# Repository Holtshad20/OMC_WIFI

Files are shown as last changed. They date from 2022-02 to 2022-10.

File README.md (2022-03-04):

# OMC WIFI

Proyecto de dispositivo medidor/protector conectado a una red a través de Wi-Fi y monitoreado con un servidor inicialmente interno a la red.

## Dispositivo medidor

### Hardware
Versión actual: 1.0\
Estado: Diseño PCB a la espera de enviar a fábrica.

**Listo**
- Diseño Esquemático KiCAD
- Diseño PCB KiCAD
- GERBERS

**Por hacer**
- Soldar componentes a PCB
- Realizar pruebas con software

Rango voltaje: 100 - 240 V RMS\
Máxima corriente: 20 A RMS - Limitado a 15 A con fusible

### Software
Versión actual: -\
Estado: Creación de códigos separados para posterior unificación.

#### Mediciones voltaje y corriente
Estado: A la espera de dispositivos que consuman mayor potencia para realizar más pruebas.

##### Listo
- Código medición voltaje y corriente.
- Realizar pruebas con distintos niveles de voltaje.

##### Por hacer
- Realizar pruebas con dispositivos que consuman mayor potencia (> 25W).

Rango voltaje: 70 - 240 V RMS\
Rango corriente: 0.2 - 15 A RMS\
*Nota:* Los mímimos en las lecturas se deben al ruido en la conversión AD. Es probable que se reduzca el ruido en PCB.

#### Accionamiento de relay
Estado: En proceso de desarrollo y pruebas

##### Listo
- Código de accionamiento de relay de acuerdo con nivel de voltaje.
- Realizar pruebas con valores de voltaje enviados por comunicación serial.
- Histéresis.

##### Por hacer
- Accionar relay cuando haya sobrecorriente
- Realizar pruebas con mediciones de voltaje real.
- Añadir inicio retardado para caso multidispositivo.

#### Configuración inicial - Conexión Dispositivo-Wi-Fi (AutoConnect)
Estado: En proceso de desarrollo y pruebas.

##### Listo
Por redactar

##### Por hacer
Por redactar

#### Conexión con servidor
Estado: No se ha iniciado.

##### Por hacer
- Implementación de MQTT

#### Integración de códigos
Estado: No se ha iniciado.
##### Por hacer
- Buscar forma de integrar usando FreeRTOS
- Comprobar funcionamiento de códigos integrados evitando interrupciones mutuas.

## Servidor
Estado: No se ha iniciado

**Por hacer**
- Implementación de MQTT en Raspberry Pi

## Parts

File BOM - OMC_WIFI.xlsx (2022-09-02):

Item | Número de Parte (SKU) | Descripción | Link | Precio Unitario | Cantidad | Precio Extendido
1.1 | ESP32-WROOM-32E | Microcontrolador ESP32 |  | $0.00 | 1 | $0.00
1.2 | PZEM-004T | Módulo de monitorización de energía PZEM-004T |  | $0.00 | 1 | $0.00
1.3 | SLA-03VDC-SL-C | Relé 250VAC/30VDC para 3.3v (En caso de no encontrarse, buscar la versión de 5v SLA-05VDC-SL-C) |  | $0.00 | 1 | $0.00
1.4 | HLK-PM01 | Convertidor 100 - 240 VAC a 5VDC/3W |  | $0.00 | 1 | $0.00
1.5 | B07F7W91LC 8541740602 | Level Shifter HiLetgo 3.3V - 5V (4 canales IIC I2C) |  | $0.00 | 1 | $0.00
1.6 | B08CDMZMDN CK0437 | Regulador de 5V a 3.3V |  | $0.00 | 1 | $0.00
2.1 | --- | Conector de alimentación AC macho (NEMA 5-15) |  | $0.00 | 1 | $0.00
2.2 | --- | Conector de alimentación AC hembra (NEMA 5-15) |  | $0.00 | 1 | $0.00
2.3 | --- | Diodo LED SMD verde |  | $0.00 | 1 | $0.00
2.4 | --- | Diodo LED SMD rojo |  | $0.00 | 1 | $0.00
2.5 | --- | Fusible de 15A |  | $0.00 | 1 | $0.00
2.6 | --- | Socket para fusible de 15A (par) |  | $0.00 | 1 | $0.00
2.7 | --- | Cable para suminitro de 100-240 VAC (es el cable que pasa por el toroide) |  | $0.00 | 1 | $0.00
2.8 | --- | Cable para switch de encendido y apagado |  | $0.00 | 3 | $0.00
 |  | Resistencia |  | $0.00 |  | $0.00
 |  |  |  | $0.00 |  | $0.00
 |  |  |  | $0.00 |  | $0.00
 |  |  |  | $0.00 |  | $0.00
 |  |  |  | $0.00 |  | $0.00
 |  |  |  | $0.00 |  | $0.00
 |  |  |  | $0.00 |  | $0.00
 |  |  |  | $0.00 |  | $0.00
 |  |  |  | $0.00 |  | $0.00
 |  |  |  | $0.00 |  | $0.00
 |  |  |  | Total $ |  | $0.00

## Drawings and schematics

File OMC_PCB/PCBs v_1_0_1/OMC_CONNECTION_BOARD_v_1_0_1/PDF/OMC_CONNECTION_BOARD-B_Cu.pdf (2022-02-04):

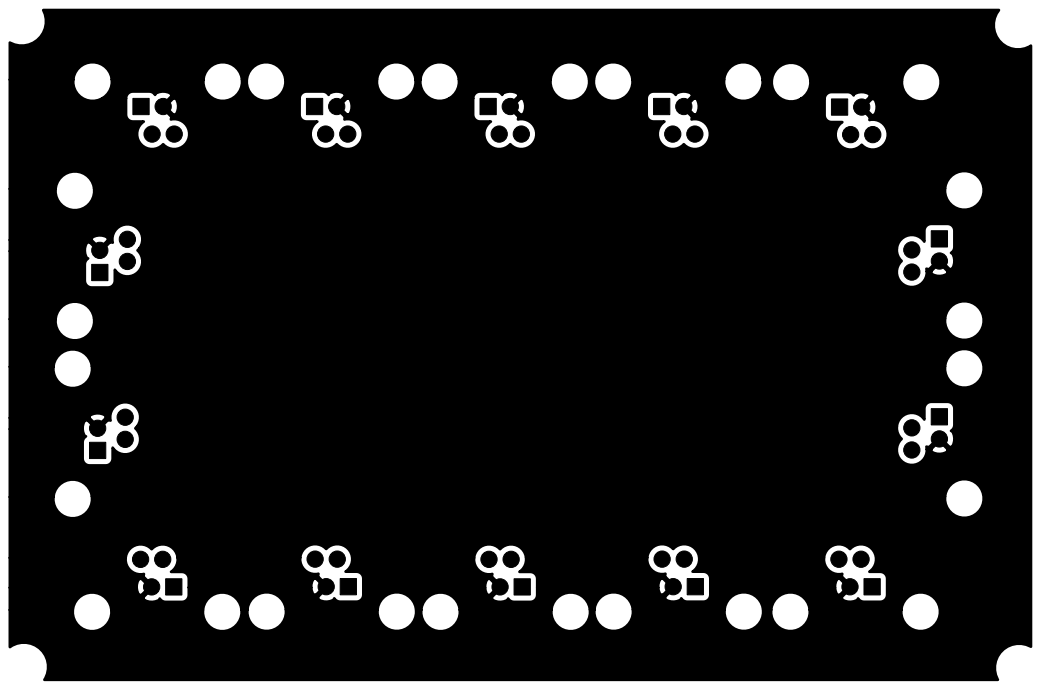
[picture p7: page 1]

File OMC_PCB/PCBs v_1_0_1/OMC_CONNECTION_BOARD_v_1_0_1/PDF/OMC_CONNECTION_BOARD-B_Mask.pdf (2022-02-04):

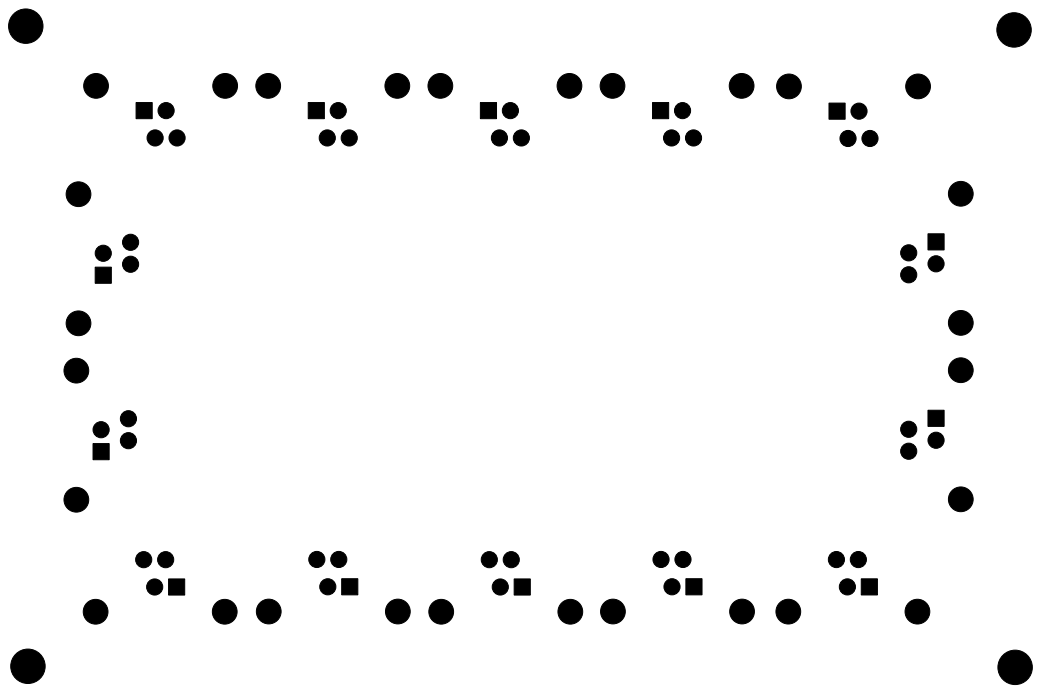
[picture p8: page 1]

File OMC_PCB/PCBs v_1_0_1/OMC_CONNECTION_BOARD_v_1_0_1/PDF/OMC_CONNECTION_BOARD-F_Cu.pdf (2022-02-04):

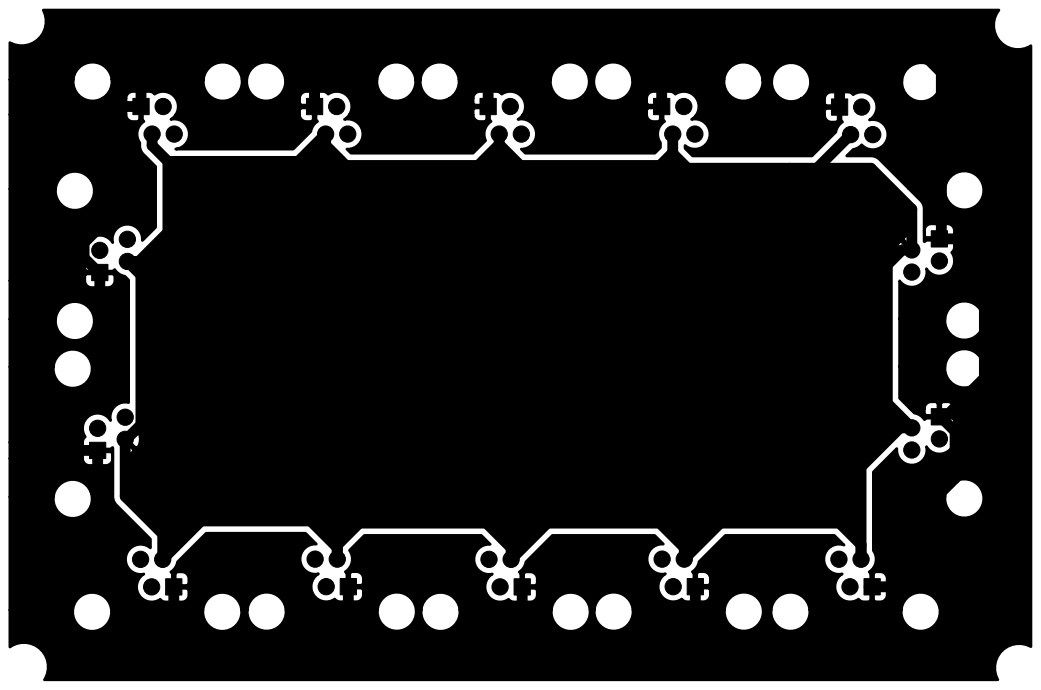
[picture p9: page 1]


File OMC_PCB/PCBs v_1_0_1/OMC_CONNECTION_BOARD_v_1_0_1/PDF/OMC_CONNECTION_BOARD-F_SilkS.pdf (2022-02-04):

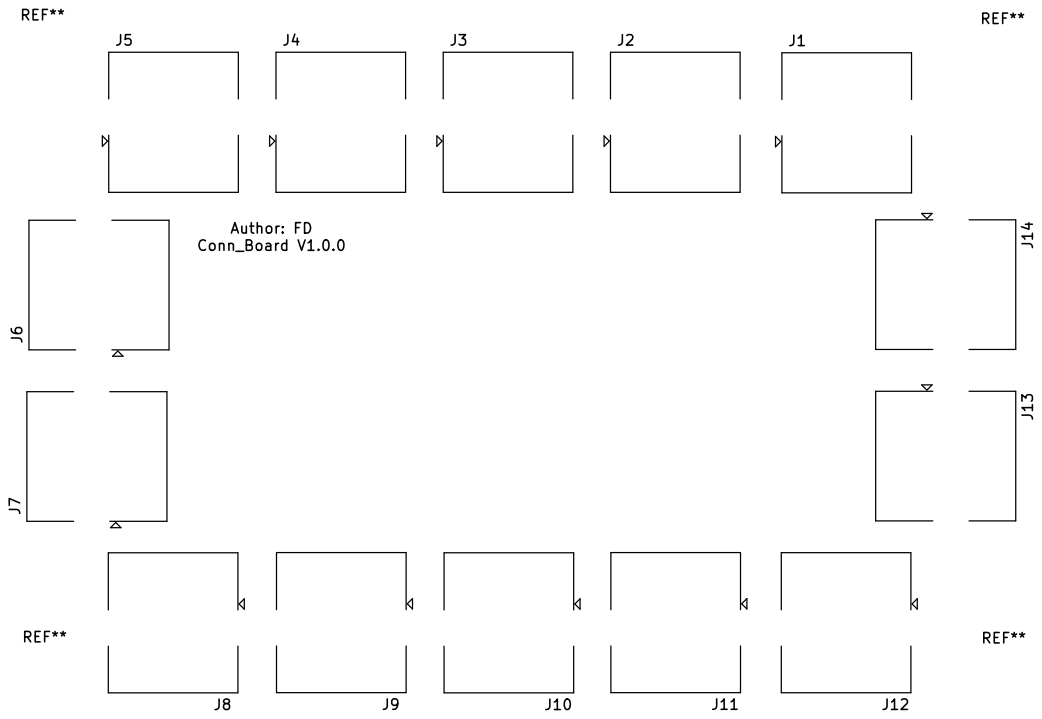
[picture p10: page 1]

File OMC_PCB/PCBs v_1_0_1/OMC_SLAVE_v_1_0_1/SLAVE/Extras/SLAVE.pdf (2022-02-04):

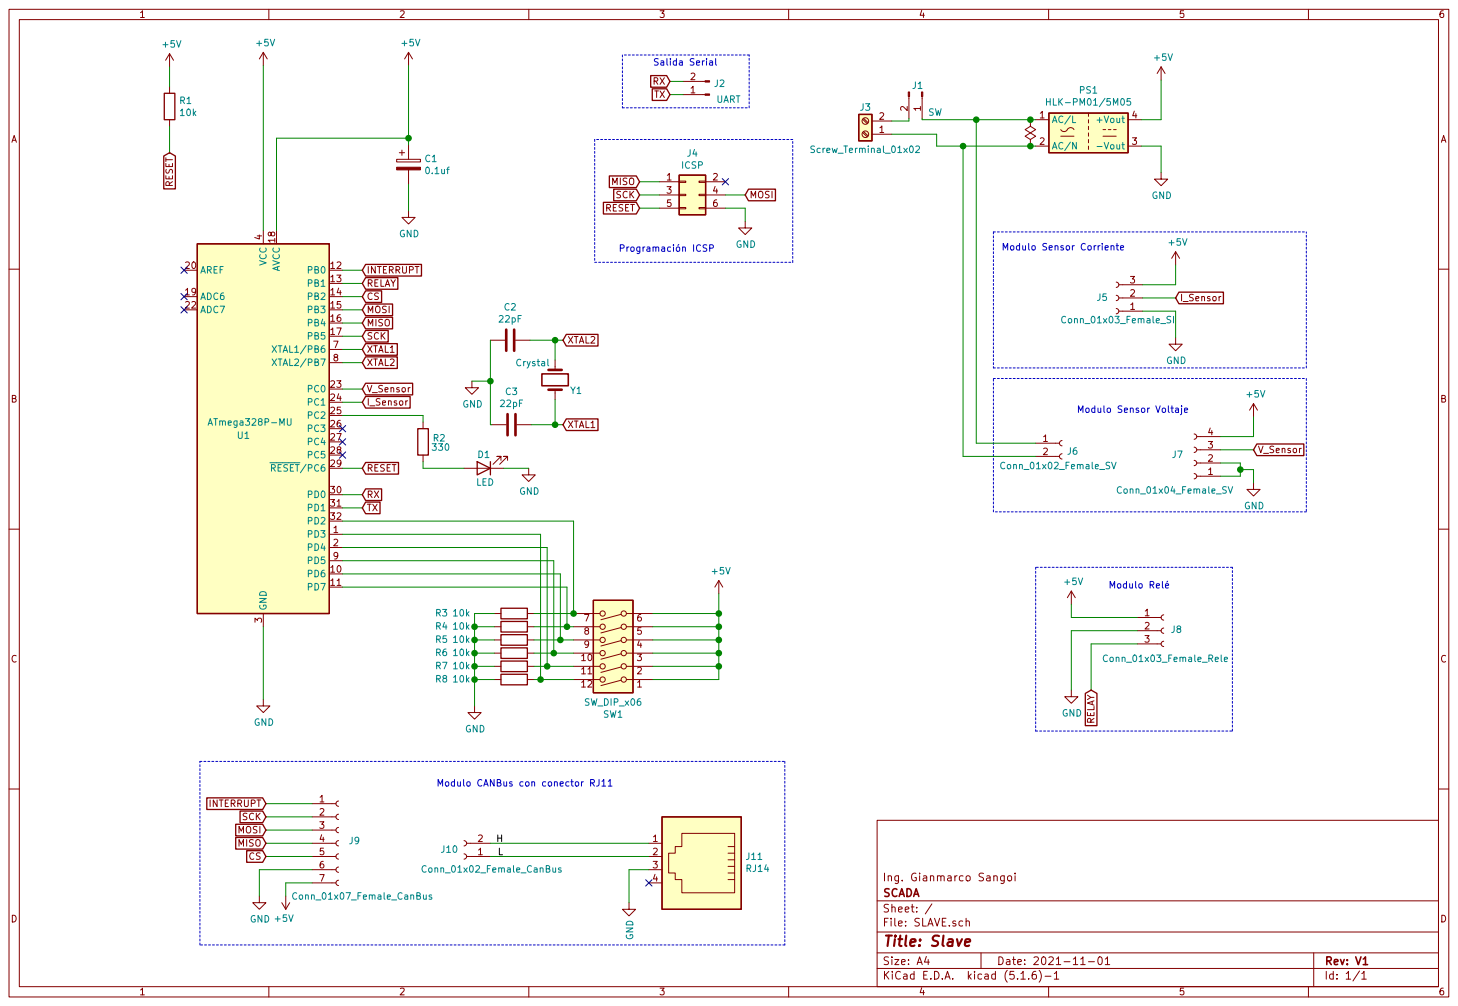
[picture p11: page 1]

Ing. Gianmarco Sangoi
File: SLAVE.sch Sheet: / SCADA

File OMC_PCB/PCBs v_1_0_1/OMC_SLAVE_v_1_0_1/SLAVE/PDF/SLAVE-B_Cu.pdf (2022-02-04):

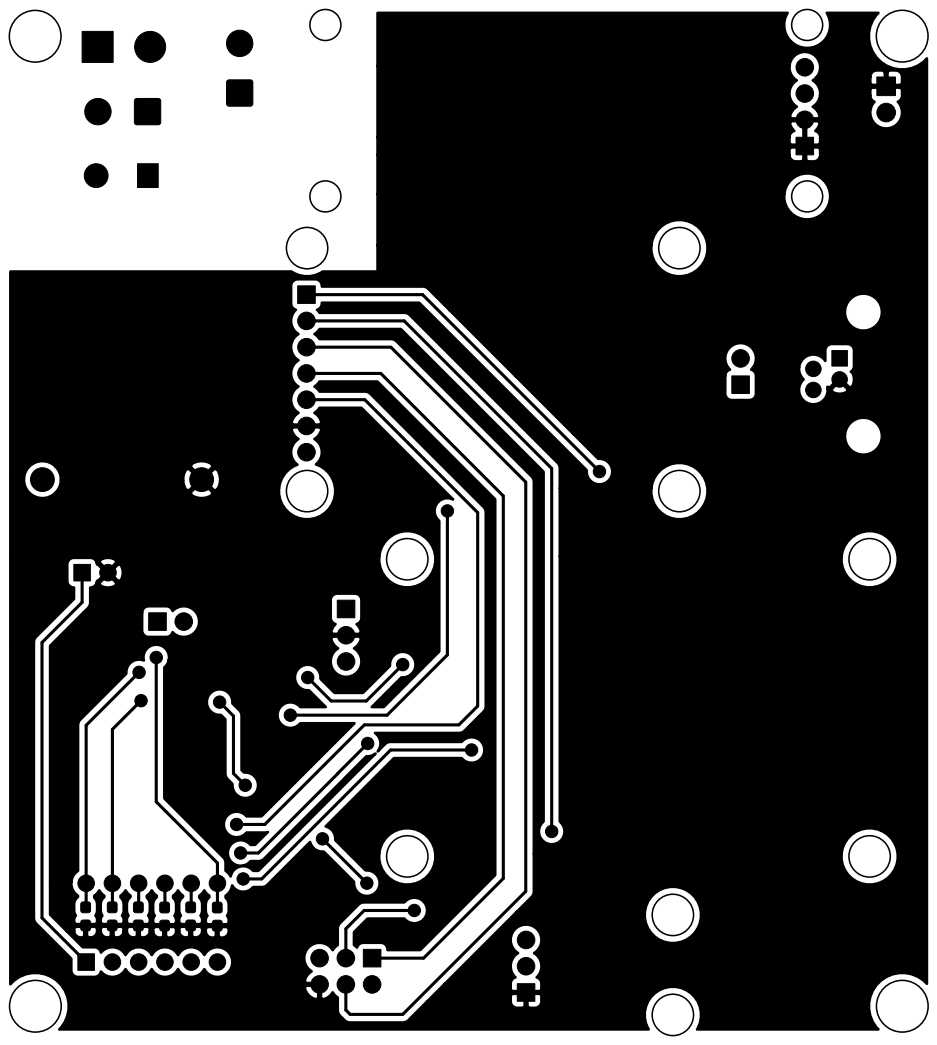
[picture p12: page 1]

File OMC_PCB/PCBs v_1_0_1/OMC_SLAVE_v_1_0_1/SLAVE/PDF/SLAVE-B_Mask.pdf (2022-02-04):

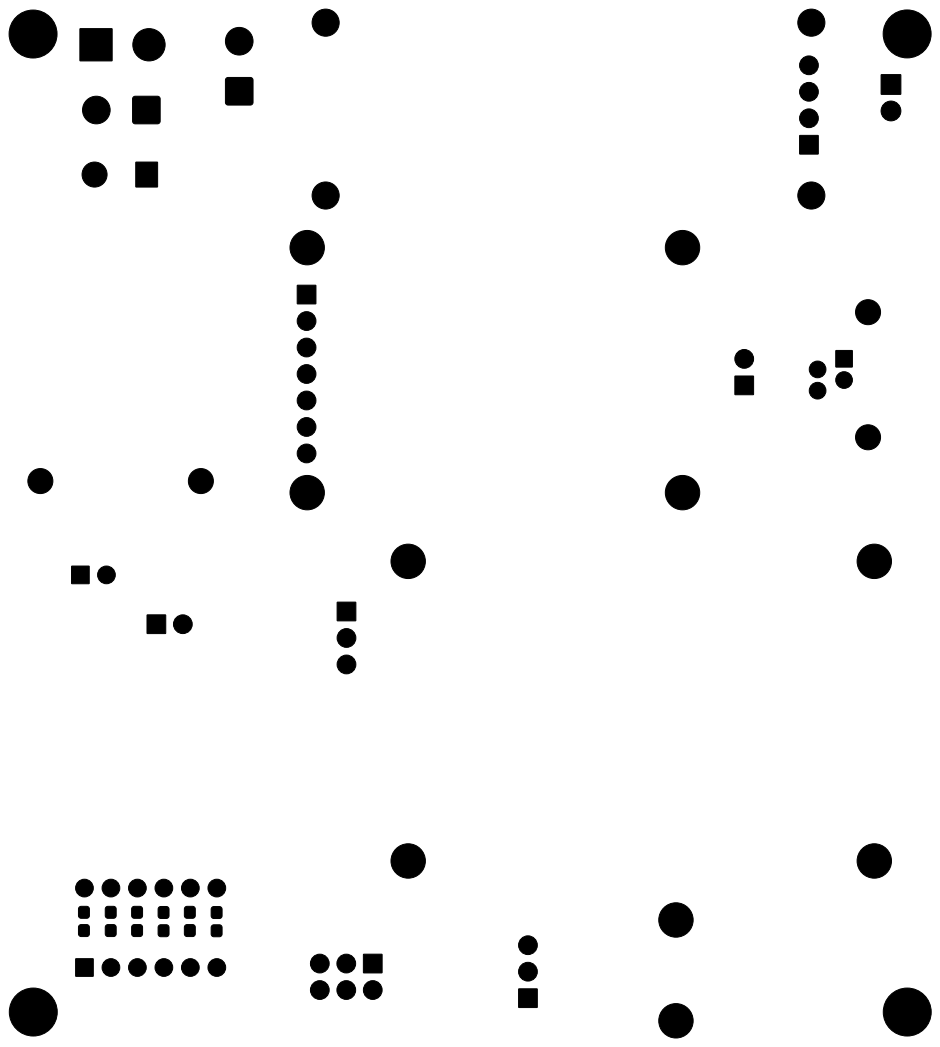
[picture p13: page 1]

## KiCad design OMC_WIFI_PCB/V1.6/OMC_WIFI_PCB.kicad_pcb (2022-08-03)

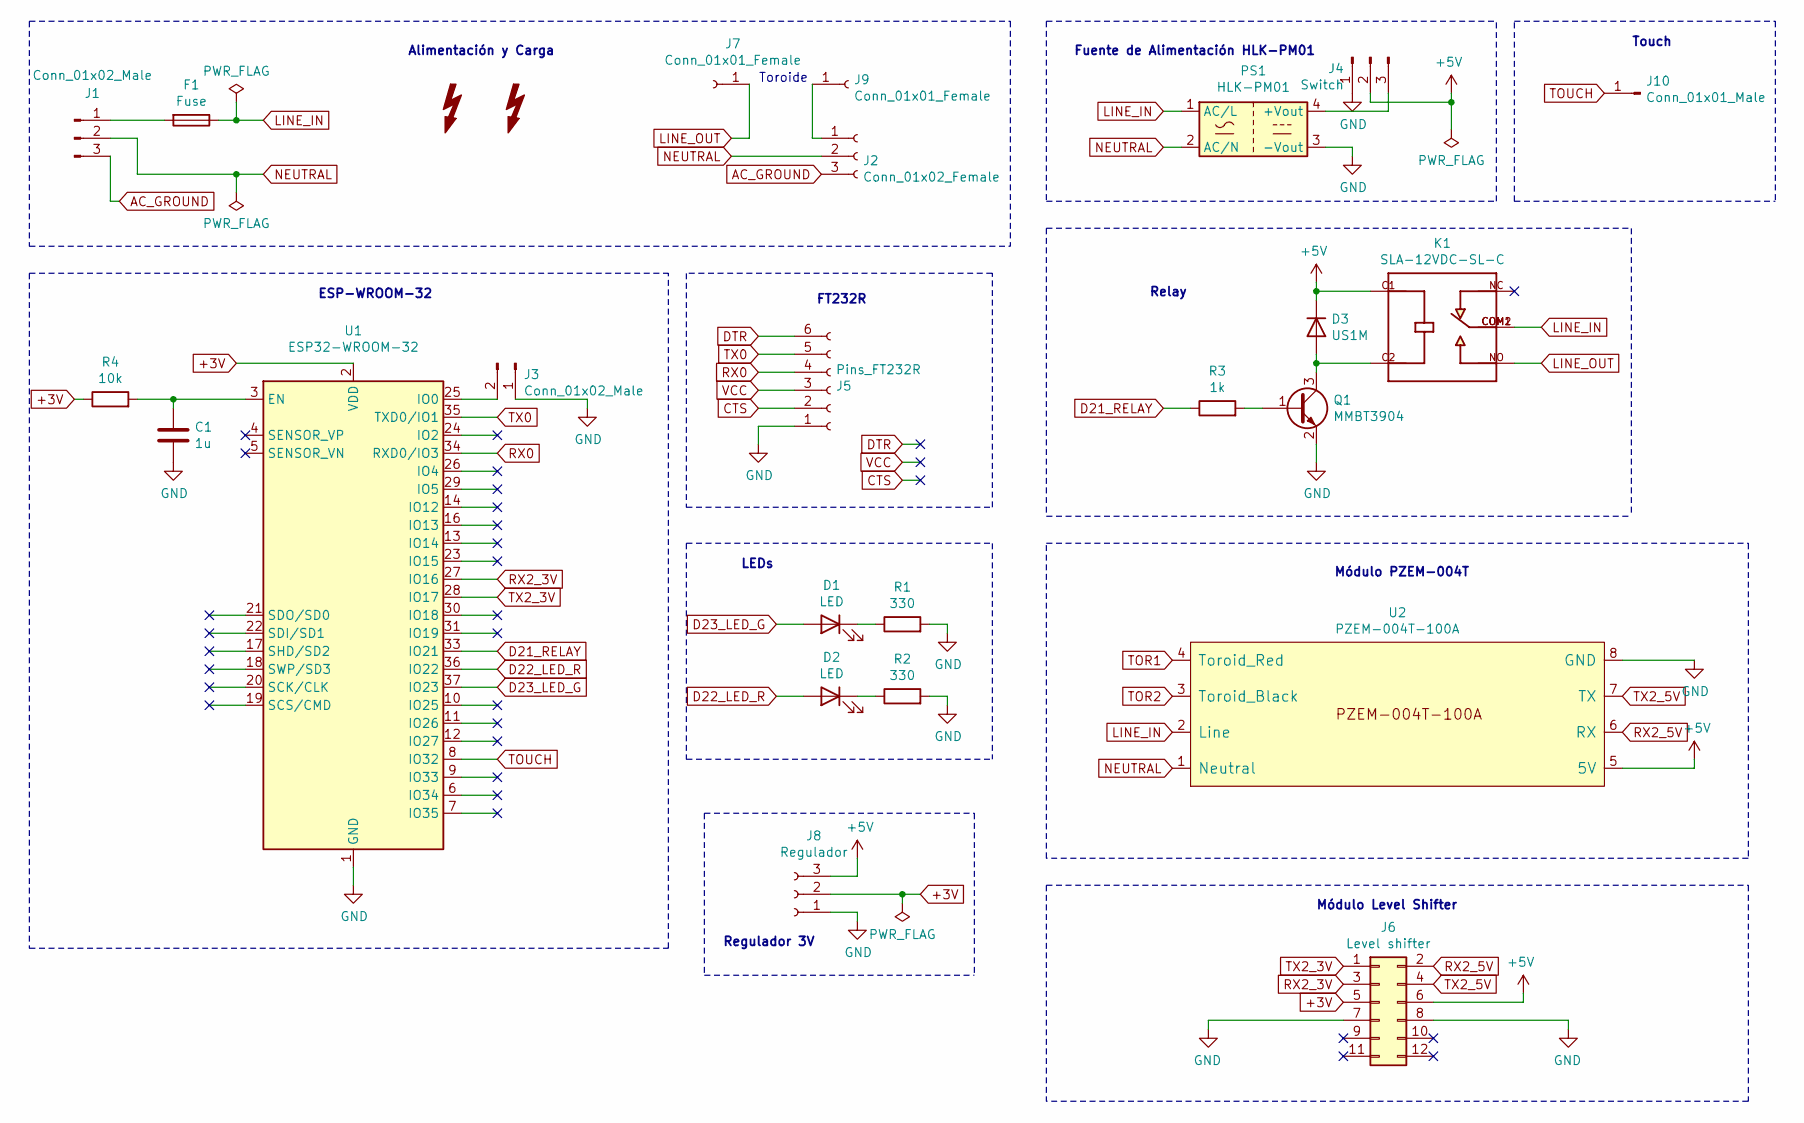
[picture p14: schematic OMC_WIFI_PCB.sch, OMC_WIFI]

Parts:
C1: 1u; C_0603_1608Metric_Pad1.08x0.95mm_HandSolder
D1, D2: LED; LED_0603_1608Metric_Pad1.05x0.95mm_HandSolder
D3: US1M; D_SMA
F1: Fuse; Fuseholder5x20_horiz_open_inline_Type-I
J1: Conn_01x02_Male; NEMA_5_P
J2: Conn_01x02_Female; NEMA_5_R
J3: Conn_01x02_Male; PinHeader_1x02_P2.54mm_Vertical
J4: Switch; PinHeader_1x03_P2.54mm_Vertical
J5: Pins_FT232R; PinSocket_1x06_P2.54mm_Vertical
J6: Level shifter; Level_Shifter_3V_5V
J7, J9: Conn_01x01_Female; SolderWire-1.5sqmm_1x01_D1.7mm_OD3mm
J8: Regulador; PinHeader_1x03_P2.54mm_Vertical
J10: Conn_01x01_Male; PinHeader_1x01_P2.54mm_Vertical
K1: SLA-12VDC-SL-C; RELAY_SLA-12VDC-SL-C
PS1: HLK-PM01; Converter_ACDC_HiLink_HLK-PMxx
Q1: MMBT3904; SOT-23
R1, R2: 330; R_0603_1608Metric_Pad0.98x0.95mm_HandSolder
R3: 1k; R_0603_1608Metric_Pad0.98x0.95mm_HandSolder
R4: 10k; R_0603_1608Metric_Pad0.98x0.95mm_HandSolder
SYM1, SYM2: SYM_Flash_Small; Symbol_HighVoltage_Type2_CopperTop_VerySmall
U1: ESP32-WROOM-32
U2: PZEM-004T-100A; PZEM-OO4T-100A

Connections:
+3V: J6.5, J8.2, R4.1, U1.2 (VDD)
+5V: D3.1 (K), J4.2, J6.6, J8.3, K1.C1, U2.5 (5V)
AC_GROUND: J1.3, J2.3
CTS: J5.2
D21_RELAY: R3.1, U1.33 (IO21)
D22_LED_R: D2.2 (A), U1.36 (IO22)
D23_LED_G: D1.2 (A), U1.37 (IO23)
DTR: J5.6
GND: C1.2, J3.1, J4.1, J5.1, J6.7, J6.8, J8.1, PS1.3 (-Vout), Q1.2 (E), R1.2, R2.2, U1.1 (GND), U1.15 (GND), U1.38 (GND), U1.39 (GND), U2.8 (GND)
LINE_IN: F1.1, K1.COM1, K1.COM2, PS1.1 (AC/L), U2.2 (Line)
LINE_OUT: J7.1, K1.NO
NEUTRAL: J1.2, J2.2, PS1.2 (AC/N), U2.1 (Neutral)
unnamed: C1.1, R4.2, U1.3 (EN)
unnamed: D1.1 (K), R1.1
unnamed: D2.1 (K), R2.1
unnamed: D3.2 (A), K1.C2, Q1.3 (C)
unnamed: F1.2, J1.1
unnamed: J2.1, J9.1
unnamed: J3.2, U1.25 (IO0)
unnamed: J4.3, PS1.4 (+Vout)
unnamed: Q1.1 (B), R3.2
RX0: J5.4, U1.34 (RXD0/IO3)
RX2_3V: J6.3, U1.27 (IO16)
RX2_5V: J6.2, U2.6 (RX)
TOR1: U2.4 (Toroid_Red)
TOR2: U2.3 (Toroid_Black)
TOUCH: J10.1, U1.8 (IO32)
TX0: J5.5, U1.35 (TXD0/IO1)
TX2_3V: J6.1, U1.28 (IO17)
TX2_5V: J6.4, U2.7 (TX)
VCC: J5.3

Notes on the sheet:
ESP-WROOM-32
Alimentación y Carga
LEDs
Fuente de Alimentación HLK-PM01
FT232R
Módulo Level Shifter
Regulador 3V
Módulo PZEM-004T
Relay
Toroide
Touch

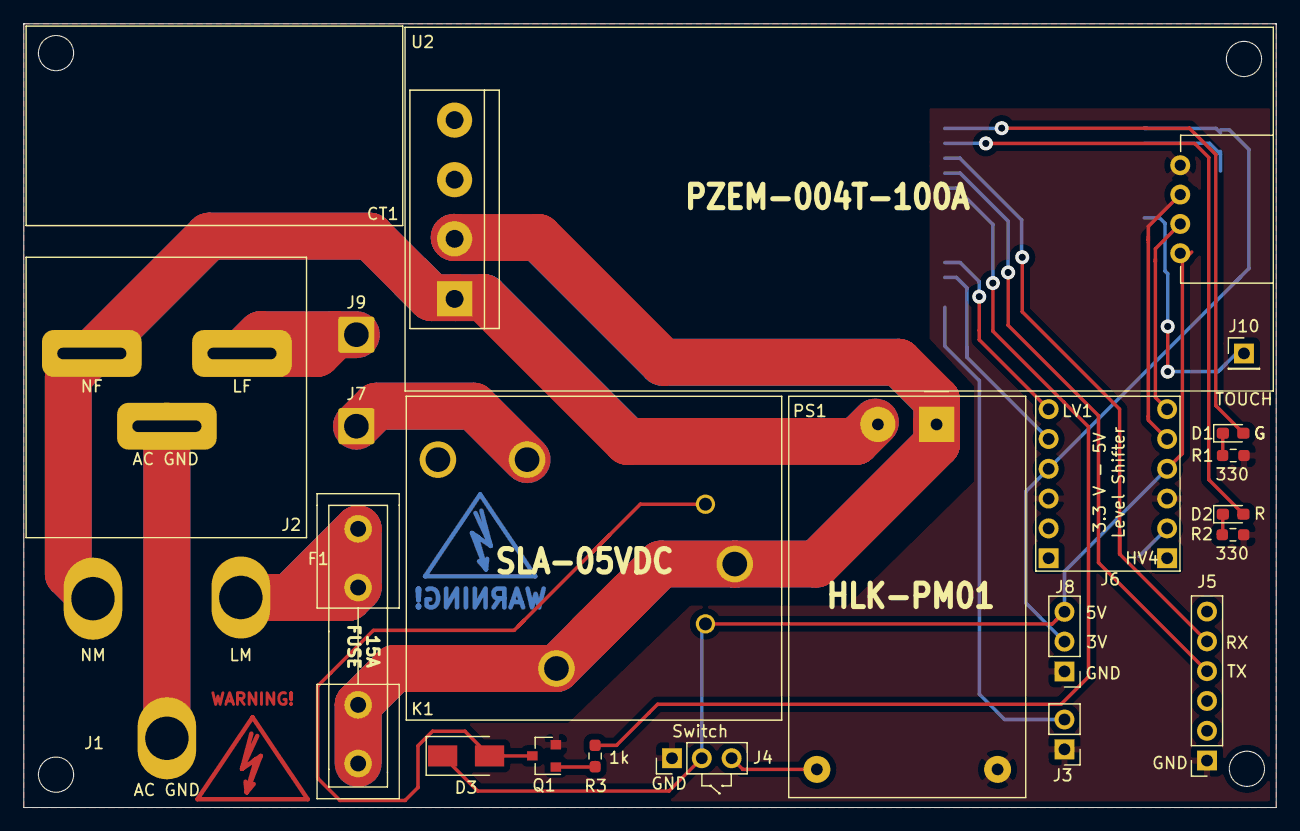
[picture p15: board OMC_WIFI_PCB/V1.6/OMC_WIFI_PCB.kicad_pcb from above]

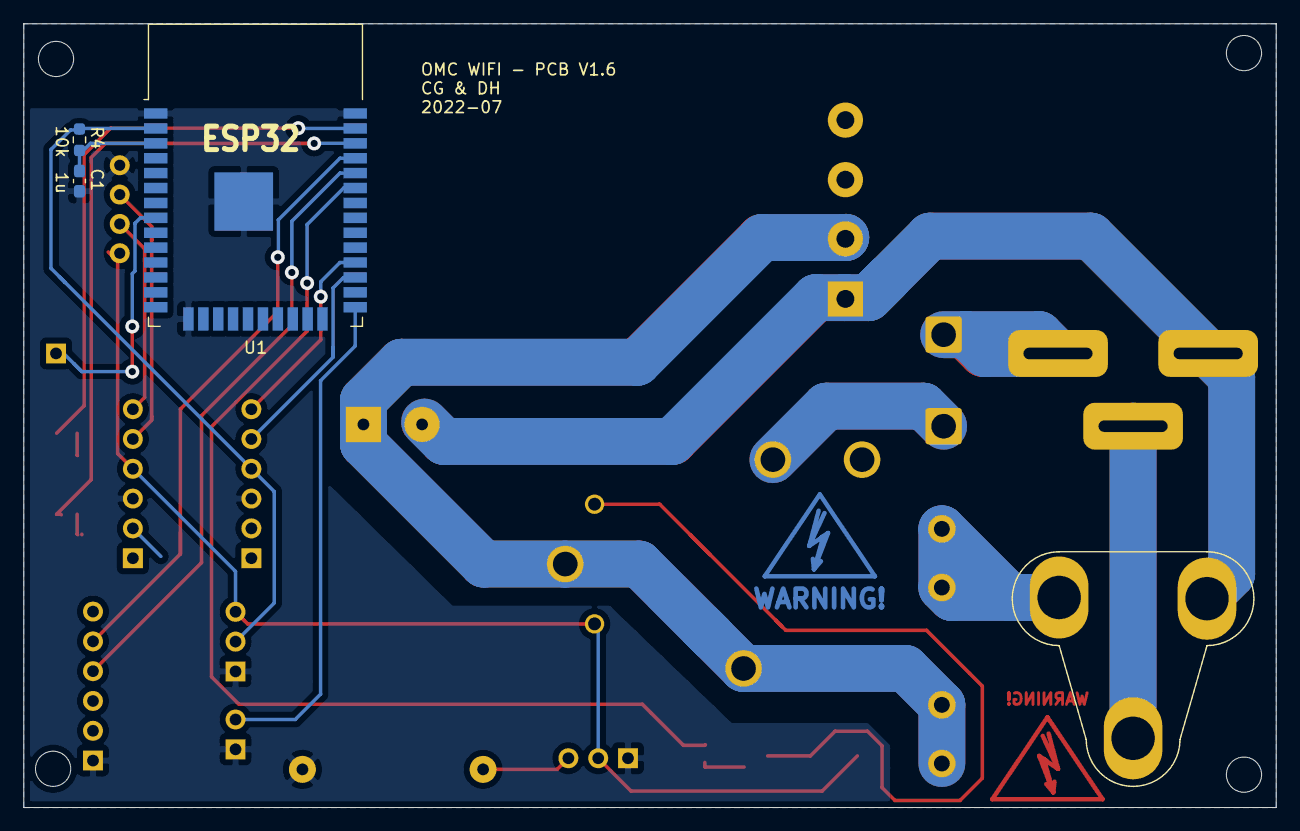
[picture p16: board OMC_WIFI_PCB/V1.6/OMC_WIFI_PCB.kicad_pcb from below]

Board: 2 copper layers, 106.8 x 66.8 mm, 26 parts (4 on the bottom side), 26 nets.

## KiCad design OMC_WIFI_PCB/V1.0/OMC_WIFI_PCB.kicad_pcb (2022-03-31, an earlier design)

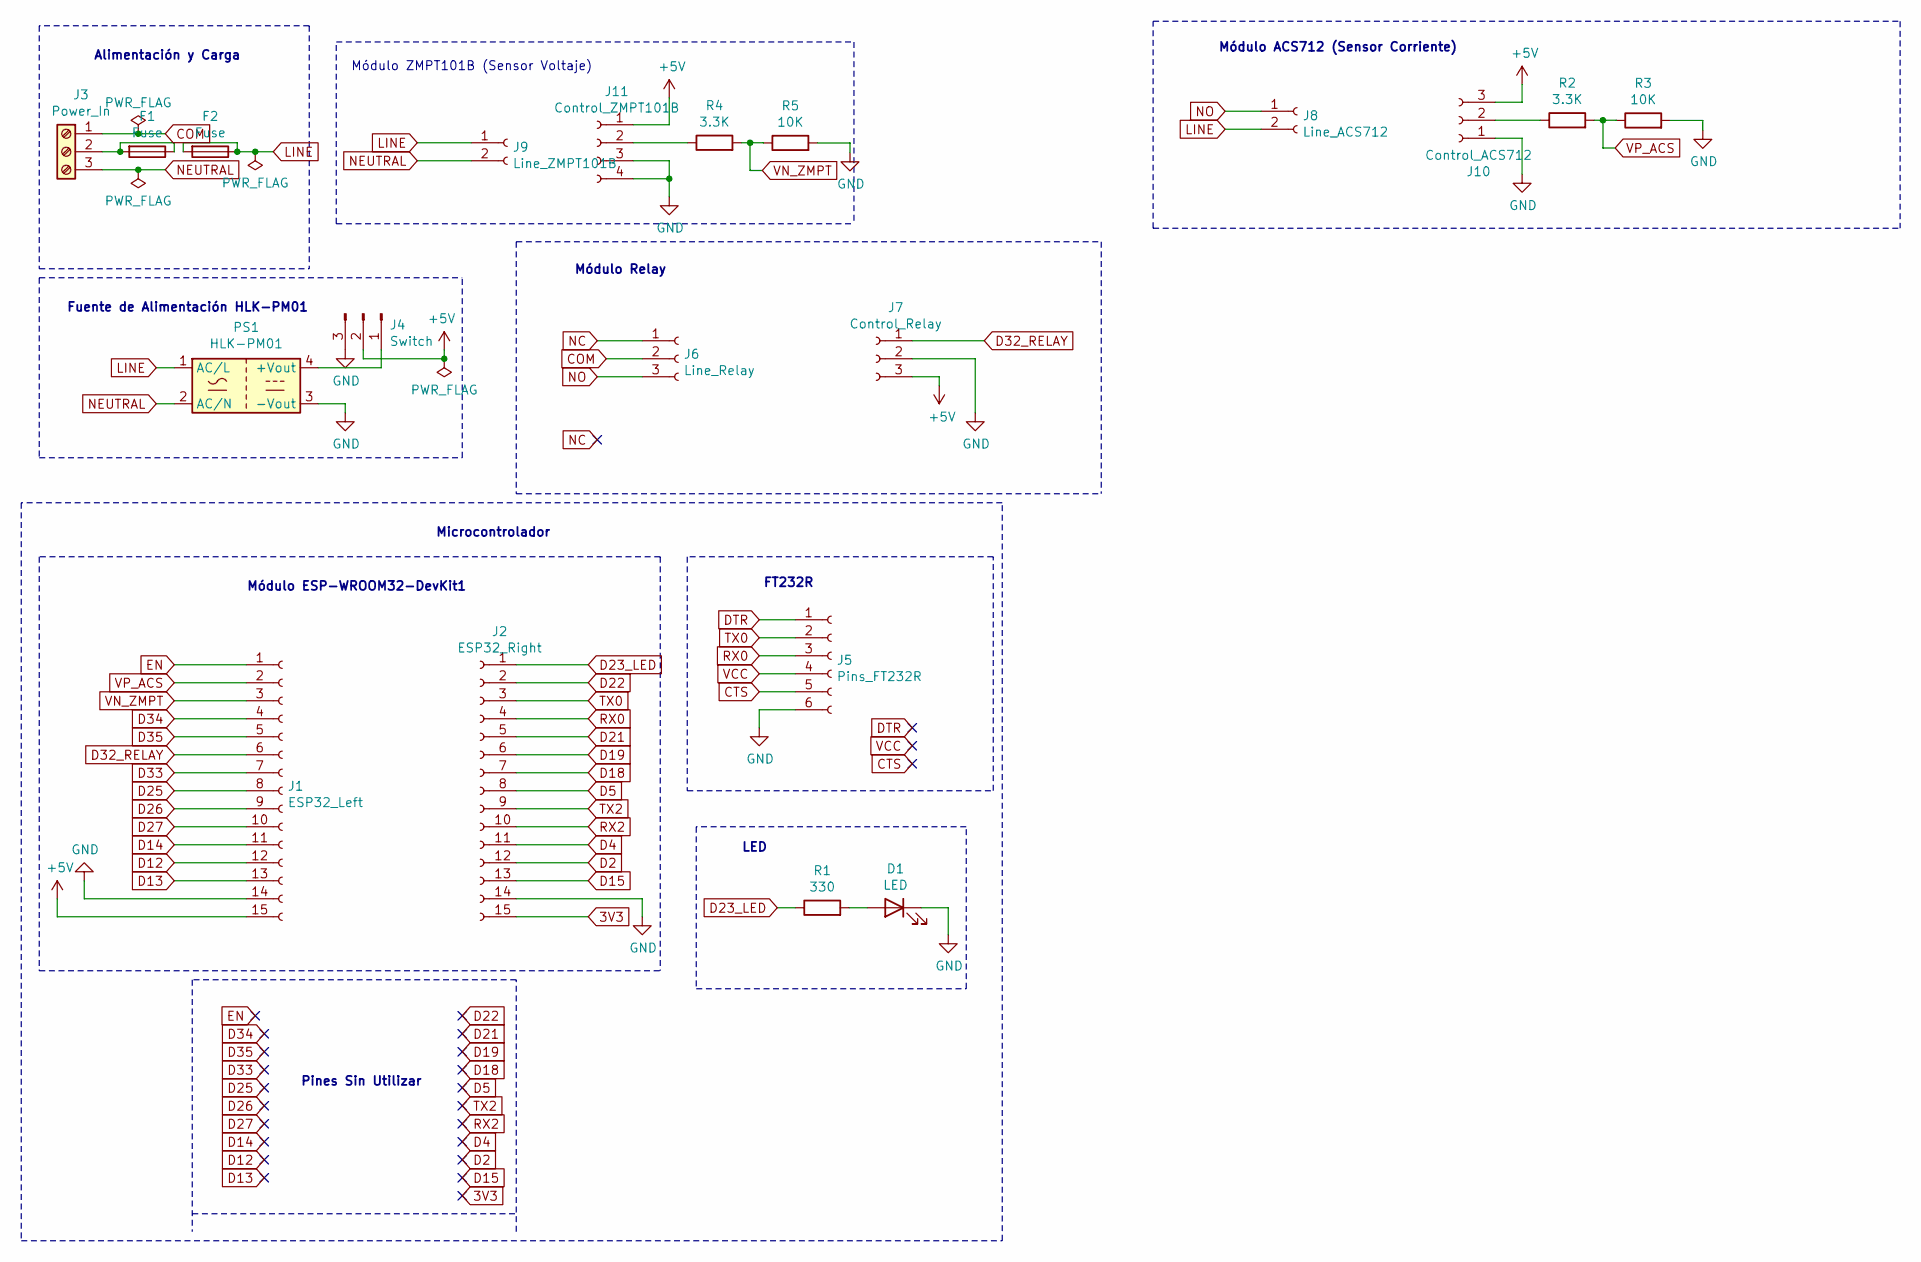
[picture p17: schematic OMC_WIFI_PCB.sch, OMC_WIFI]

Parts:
D1: LED; LED_D3.0mm
F1, F2: Fuse; Fuse_Littelfuse_395Series
J1: ESP32_Left; PinSocket_1x15_P2.54mm_Vertical
J2: ESP32_Right; PinSocket_1x15_P2.54mm_Vertical
J3: Power_In; TE_5-1437652-4
J4: Switch; SolderWire-0.75sqmm_1x03_P4.8mm_D1.25mm_OD2.3mm
J5: Pins_FT232R; PinSocket_1x06_P2.54mm_Vertical
J6: Line_Relay; TerminalBlock_bornier-3_P5.08mm
J7: Control_Relay; TerminalBlock_bornier-3_P5.08mm
J8: Line_ACS712; TerminalBlock_bornier-2_P5.08mm
J9: Line_ZMPT101B; TerminalBlock_bornier-2_P5.08mm
J10: Control_ACS712; PinHeader_1x03_P2.54mm_Vertical
J11: Control_ZMPT101B; PinHeader_1x04_P2.54mm_Vertical
PS1: HLK-PM01; Converter_ACDC_HiLink_HLK-PMxx
R1: 330; R_2010_5025Metric_Pad1.40x2.65mm_HandSolder
R2, R4: 3.3K; R_2010_5025Metric_Pad1.40x2.65mm_HandSolder
R3, R5: 10K; R_2010_5025Metric_Pad1.40x2.65mm_HandSolder

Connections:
3V3: J2.15
+5V: J1.15, J4.2, J7.3, J10.3, J11.1
COM: J3.1, J6.2
CTS: J5.5
D2: J2.12
D4: J2.11
D5: J2.8
D12: J1.12
D13: J1.13
D14: J1.11
D15: J2.13
D18: J2.7
D19: J2.6
D21: J2.5
D22: J2.2
D23_LED: J2.1, R1.1
D25: J1.8
D26: J1.9
D27: J1.10
D32_RELAY: J1.6, J7.1
D33: J1.7
D34: J1.4
D35: J1.5
DTR: J5.1
EN: J1.1
GND: D1.1 (K), J1.14, J2.14, J4.3, J5.6, J7.2, J10.1, J11.3, J11.4, PS1.3 (-Vout), R3.2, R5.2
LINE: F2.1, F2.2, J8.2, J9.1, PS1.1 (AC/L)
NC: J6.1
NEUTRAL: J3.3, J9.2, PS1.2 (AC/N)
NO: J6.3, J8.1
unnamed: D1.2 (A), R1.2
unnamed: F1.1, F1.2, J3.2
unnamed: J4.1, PS1.4 (+Vout)
unnamed: J10.2, R2.1
unnamed: J11.2, R4.1
RX0: J2.4, J5.3
RX2: J2.10
TX0: J2.3, J5.2
TX2: J2.9
VCC: J5.4
VN_ZMPT: J1.3, R4.2, R5.1
VP_ACS: J1.2, R2.2, R3.1

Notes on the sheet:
Módulo ESP-WROOM32-DevKit1
Alimentación y Carga
Módulo Relay
LED
Fuente de Alimentación HLK-PM01
FT232R
Pines Sin Utilizar
Microcontrolador
Módulo ZMPT101B (Sensor Voltaje)
Módulo ACS712 (Sensor Corriente)

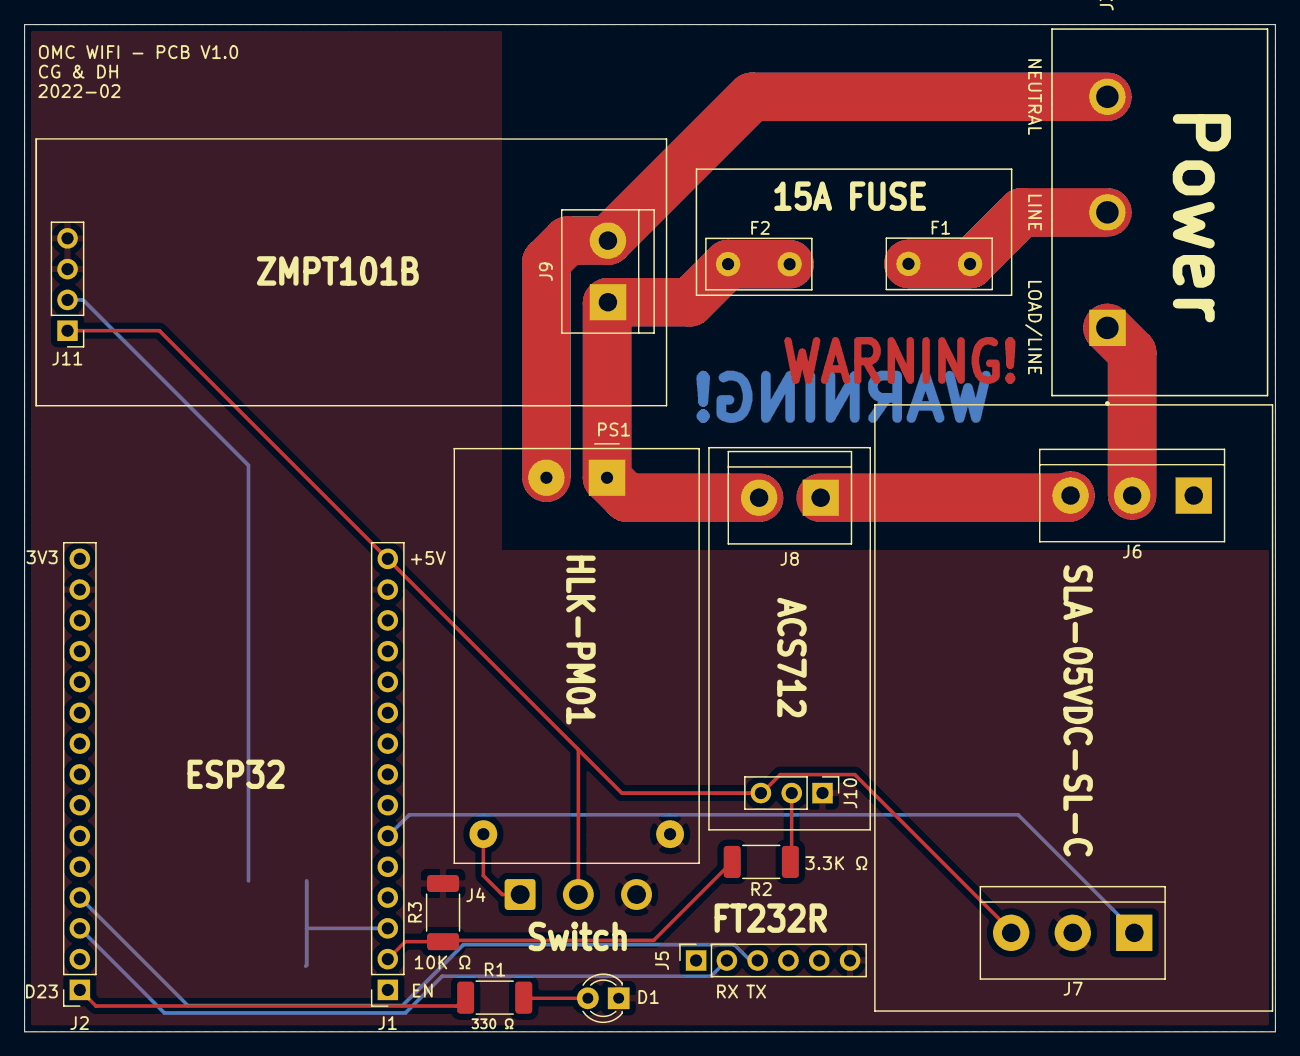
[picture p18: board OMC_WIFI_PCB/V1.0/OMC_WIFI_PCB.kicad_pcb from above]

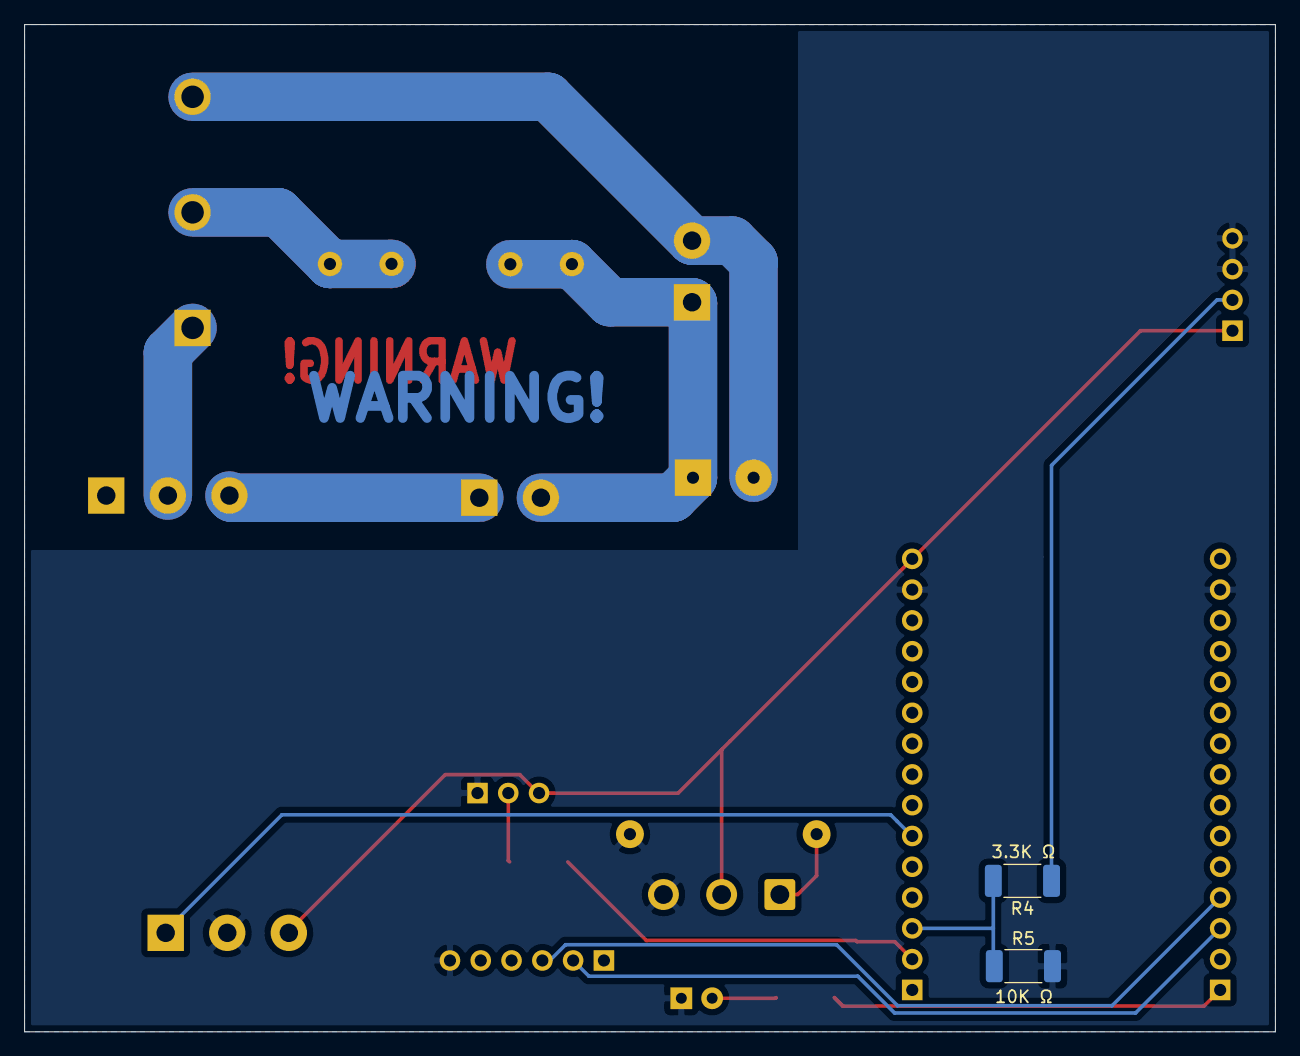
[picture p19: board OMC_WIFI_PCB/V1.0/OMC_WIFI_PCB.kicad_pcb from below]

Board: 2 copper layers, 103.2 x 83.1 mm, 20 parts (2 on the bottom side), 17 nets.

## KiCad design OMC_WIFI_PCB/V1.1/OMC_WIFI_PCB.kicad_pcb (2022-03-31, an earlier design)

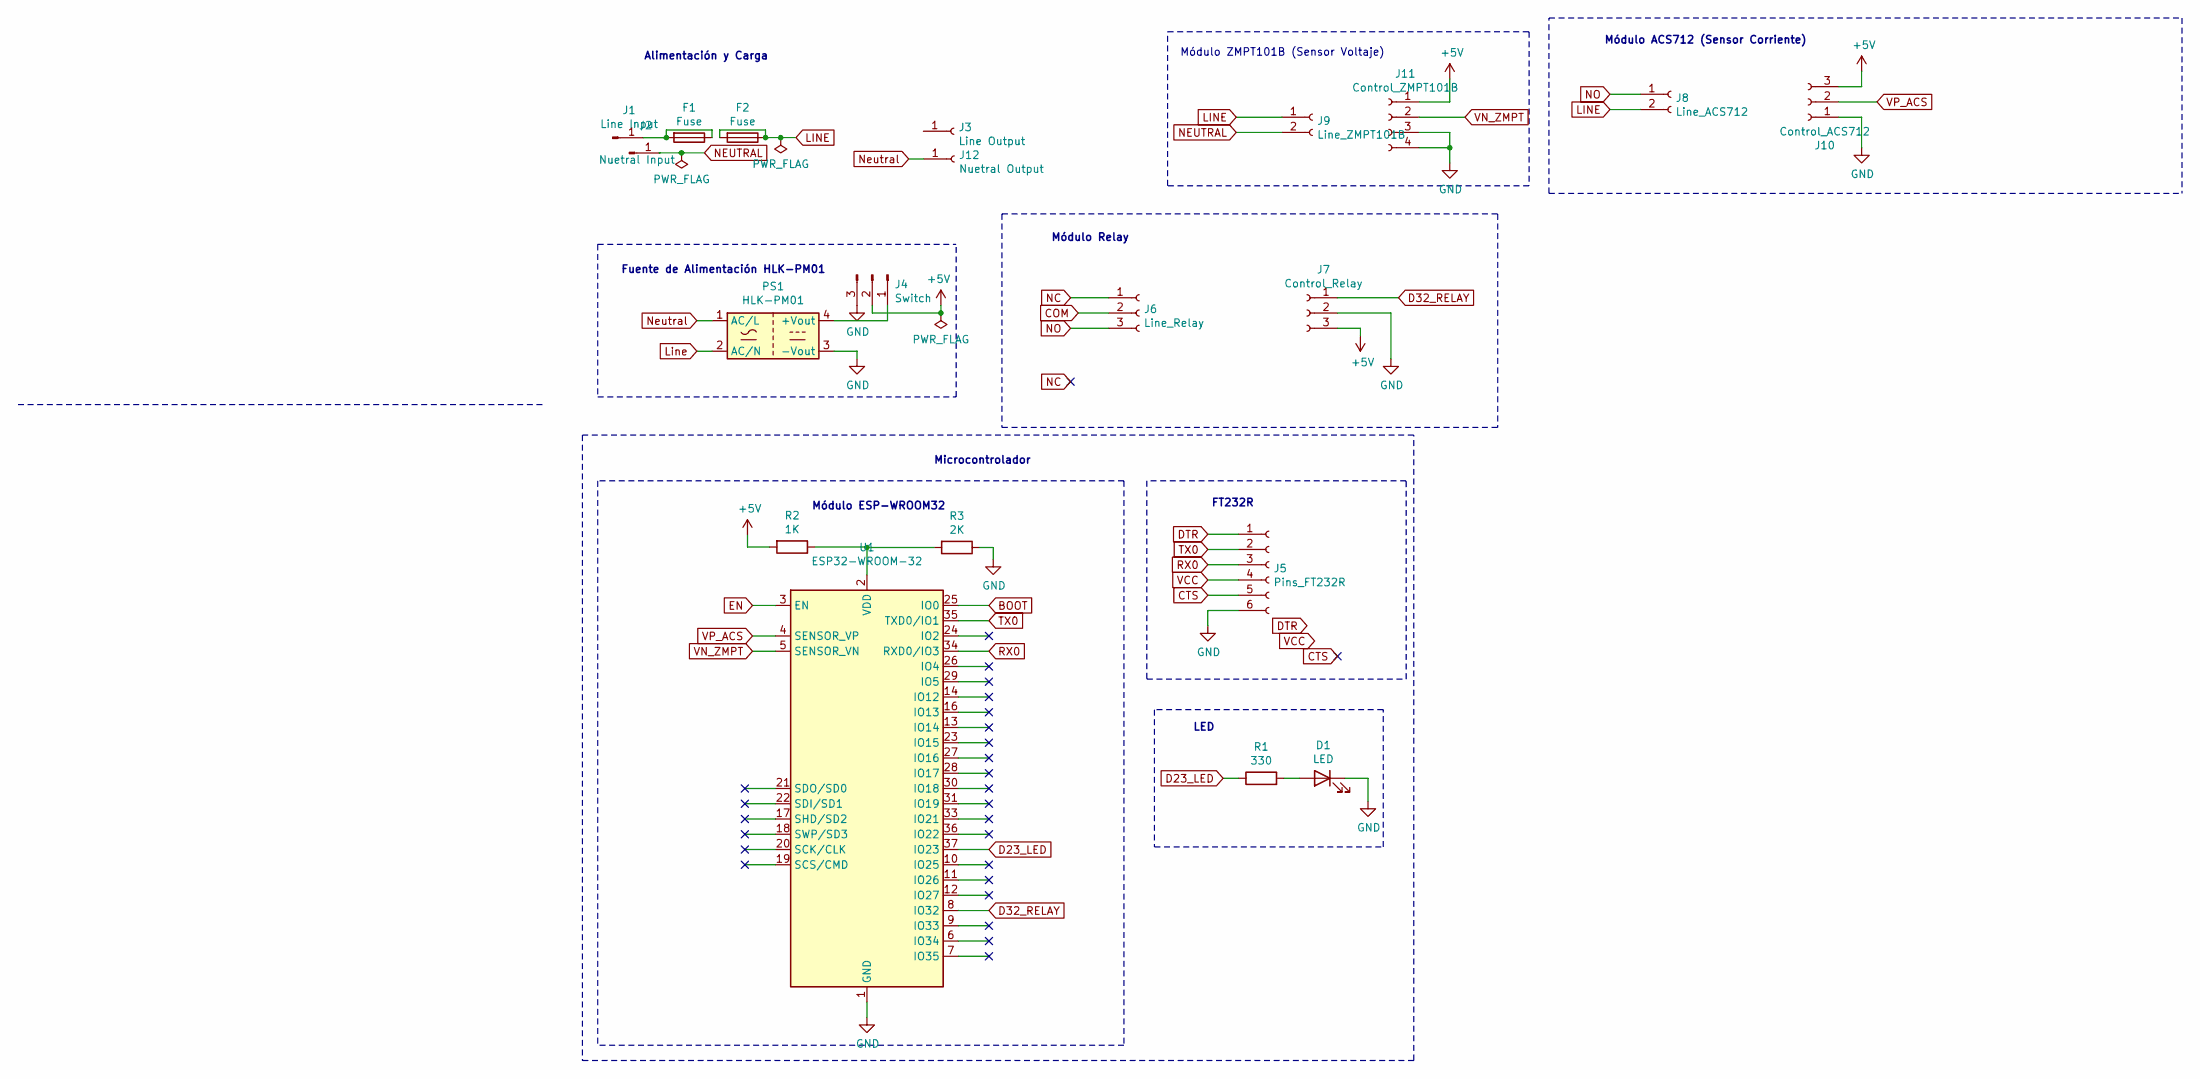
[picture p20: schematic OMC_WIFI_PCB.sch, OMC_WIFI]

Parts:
D1: LED; LED_D3.0mm
F1, F2: Fuse; Fuse_Littelfuse_395Series
J1: Line Input; OMC-Male-Plug
J2: Nuetral Input; OMC-Male-Plug
J3: Line Output; OMC-Female-Plug
J4: Switch; SolderWire-0.75sqmm_1x03_P4.8mm_D1.25mm_OD2.3mm
J5: Pins_FT232R; PinSocket_1x06_P2.54mm_Vertical
J6: Line_Relay; TerminalBlock_bornier-3_P5.08mm
J7: Control_Relay; TerminalBlock_bornier-3_P5.08mm
J8: Line_ACS712; TerminalBlock_bornier-2_P5.08mm
J9: Line_ZMPT101B; TerminalBlock_bornier-2_P5.08mm
J10: Control_ACS712; PinHeader_1x03_P2.54mm_Vertical
J11: Control_ZMPT101B; PinHeader_1x04_P2.54mm_Vertical
J12: Nuetral Output; OMC-Female-Plug
PS1: HLK-PM01; Converter_ACDC_HiLink_HLK-PMxx
R1: 330; R_2010_5025Metric_Pad1.40x2.65mm_HandSolder
R2: 1K; R_2512_6332Metric_Pad1.40x3.35mm_HandSolder
R3: 2K; R_2512_6332Metric_Pad1.40x3.35mm_HandSolder
U1: ESP32-WROOM-32

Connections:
+5V: J4.2, J7.3, J10.3, J11.1, R2.2
BOOT: U1.25 (IO0)
COM: J6.2
CTS: J5.5
D23_LED: R1.1, U1.37 (IO23)
D32_RELAY: J7.1, U1.8 (IO32)
DTR: J5.1
EN: U1.3 (EN)
GND: D1.1 (K), J4.3, J5.6, J7.2, J10.1, J11.3, J11.4, PS1.3 (-Vout), R3.1, U1.1 (GND), U1.15 (GND), U1.38 (GND), U1.39 (GND)
LINE: F2.1, F2.2, J8.2, J9.1
Line: PS1.2 (AC/N)
NC: J6.1
NEUTRAL: J2.1, J9.2
NO: J6.3, J8.1
unnamed: D1.2 (A), R1.2
unnamed: F1.1, F1.2, J1.1
unnamed: J4.1, PS1.4 (+Vout)
unnamed: R2.1, R3.2, U1.2 (VDD)
Neutral: J12.1, PS1.1 (AC/L)
RX0: J5.3, U1.34 (RXD0/IO3)
TX0: J5.2, U1.35 (TXD0/IO1)
VCC: J5.4
VN_ZMPT: J11.2, U1.5 (SENSOR_VN)
VP_ACS: J10.2, U1.4 (SENSOR_VP)

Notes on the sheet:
Módulo ESP-WROOM32
Alimentación y Carga
Módulo Relay
LED
Fuente de Alimentación HLK-PM01
FT232R
Microcontrolador
Módulo ZMPT101B (Sensor Voltaje)
Módulo ACS712 (Sensor Corriente)

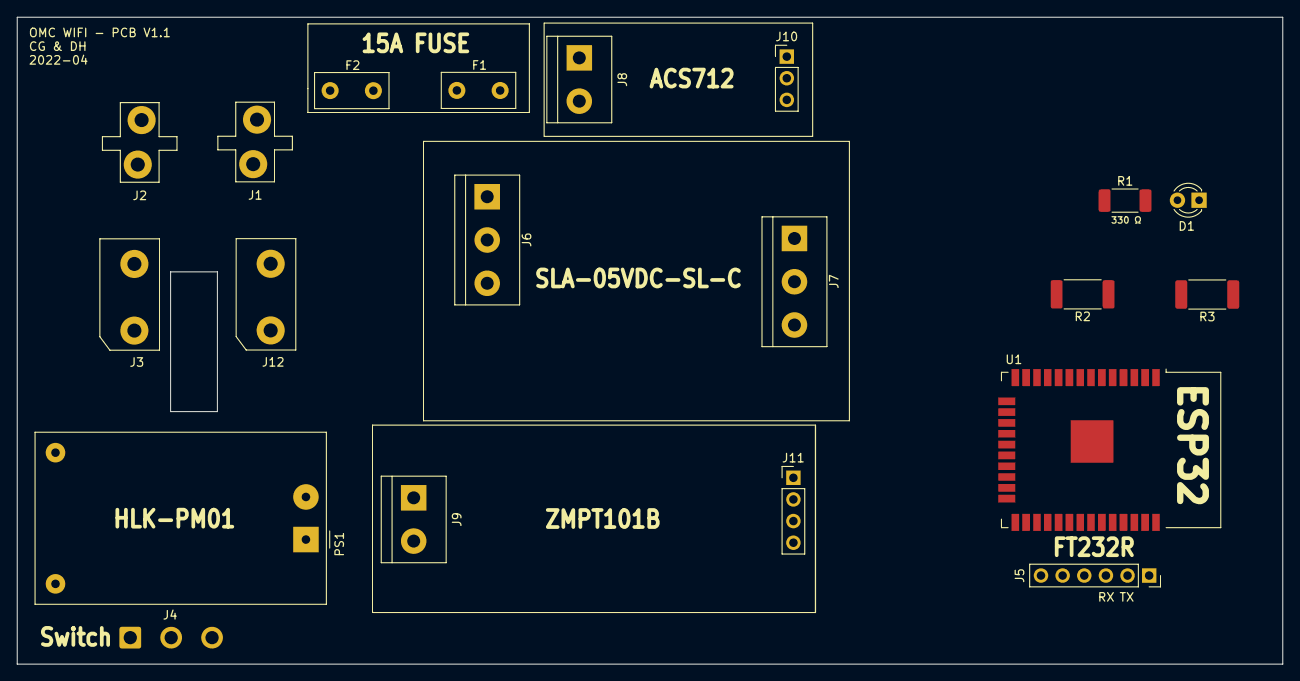
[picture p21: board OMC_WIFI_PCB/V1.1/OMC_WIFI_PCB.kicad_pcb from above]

Board: 2 copper layers, 148.6 x 75.9 mm, 20 parts (0 on the bottom side), 16 nets.

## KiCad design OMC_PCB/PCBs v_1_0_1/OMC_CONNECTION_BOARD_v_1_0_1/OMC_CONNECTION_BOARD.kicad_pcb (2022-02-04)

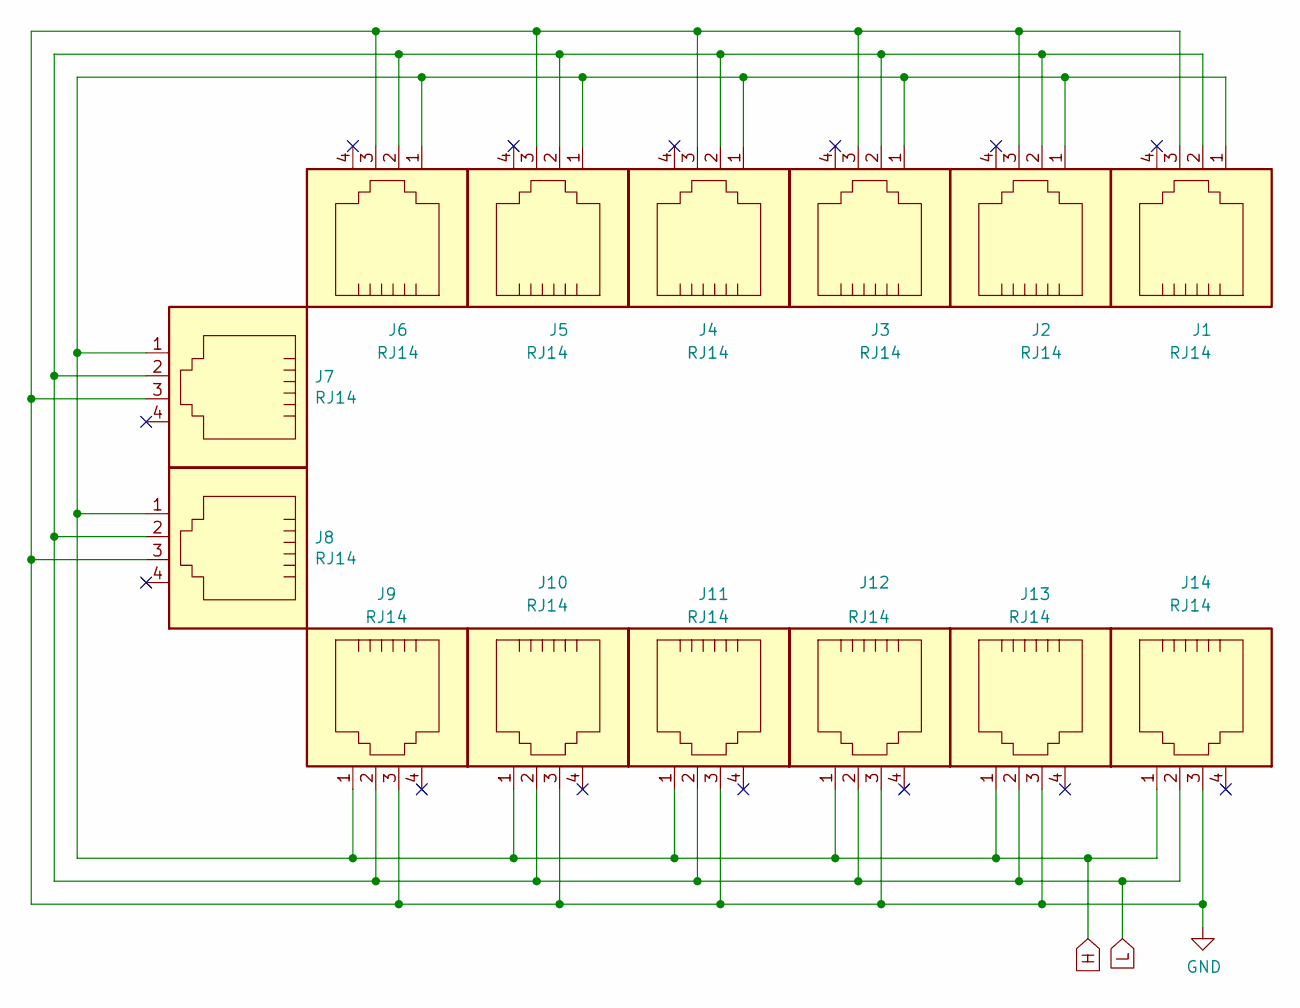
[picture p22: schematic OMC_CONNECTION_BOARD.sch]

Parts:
J1, J2, J3, J4, J5, J6, J7, J8, J9, J10, J11, J12, J13, J14: RJ14; RJ14_Connfly_DS1133-S4_Horizontal

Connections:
GND: J1.3, J2.3, J3.3, J4.3, J5.3, J6.3, J7.3, J8.3, J9.3, J10.3, J11.3, J12.3, J13.3, J14.3
H: J1.1, J2.1, J3.1, J4.1, J5.1, J6.1, J7.1, J8.1, J9.1, J10.1, J11.1, J12.1, J13.1, J14.1
L: J1.2, J2.2, J3.2, J4.2, J5.2, J6.2, J7.2, J8.2, J9.2, J10.2, J11.2, J12.2, J13.2, J14.2

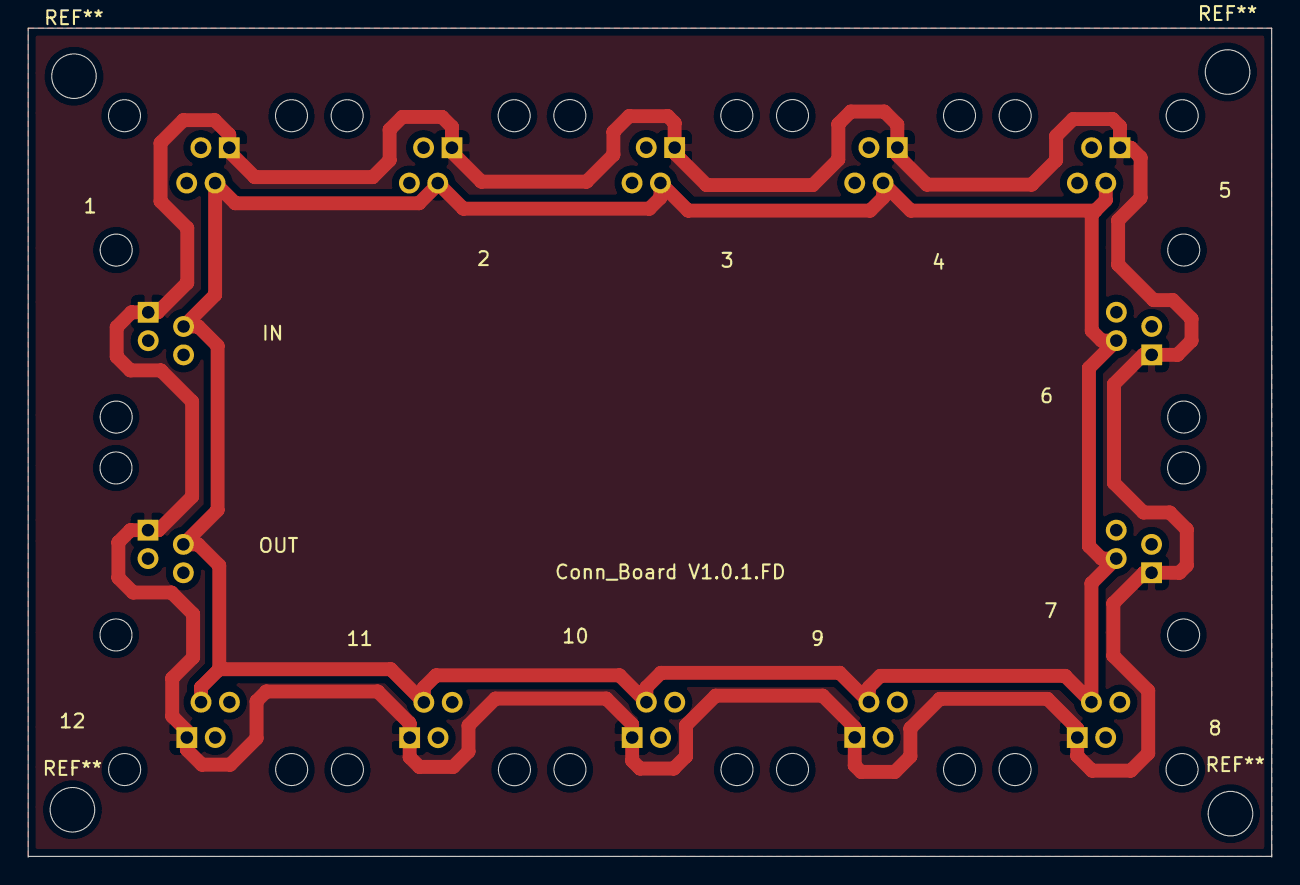
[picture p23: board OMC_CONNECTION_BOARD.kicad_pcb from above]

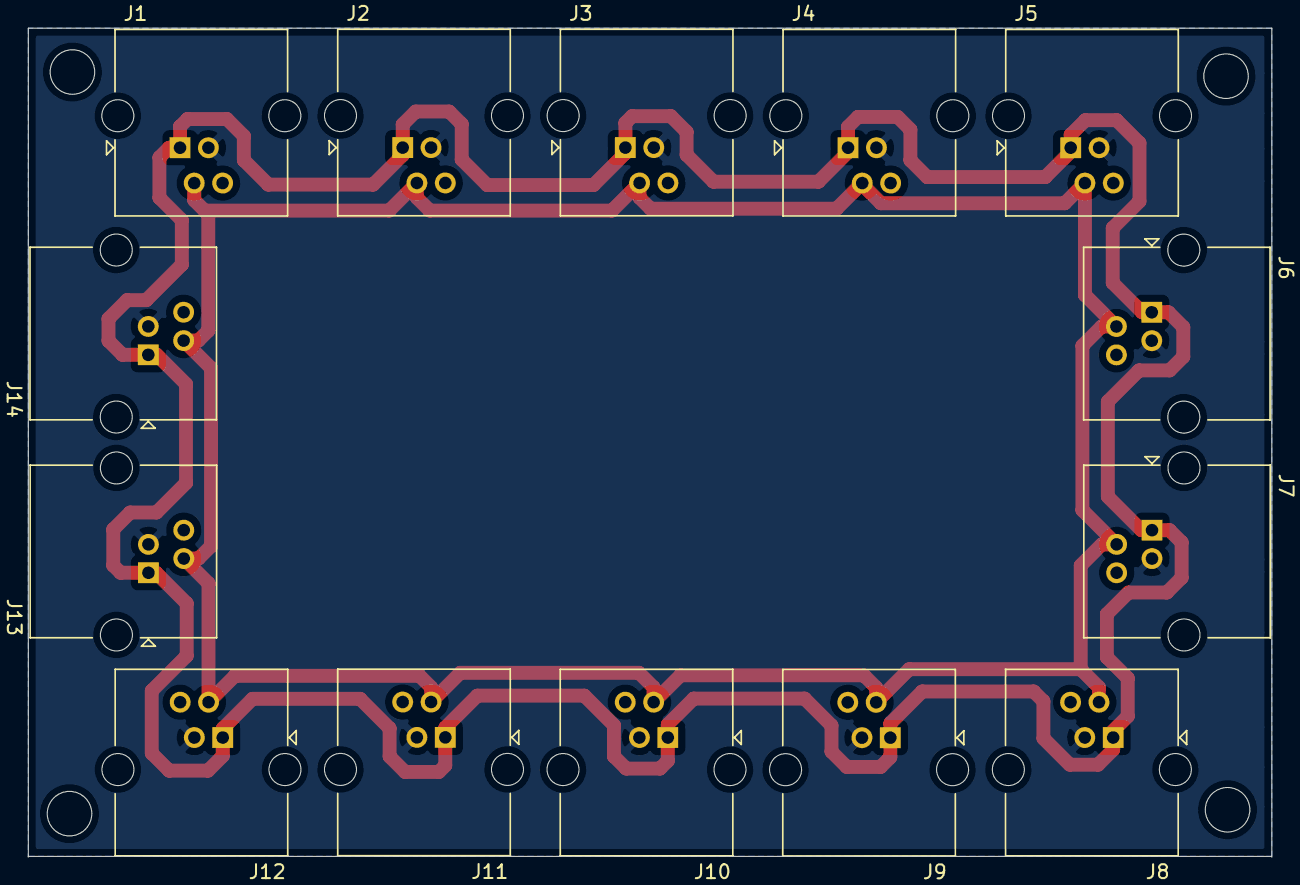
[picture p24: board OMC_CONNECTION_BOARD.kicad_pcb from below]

Board: 2 copper layers, 89.4 x 59.6 mm, 14 parts (14 on the bottom side), 3 nets.

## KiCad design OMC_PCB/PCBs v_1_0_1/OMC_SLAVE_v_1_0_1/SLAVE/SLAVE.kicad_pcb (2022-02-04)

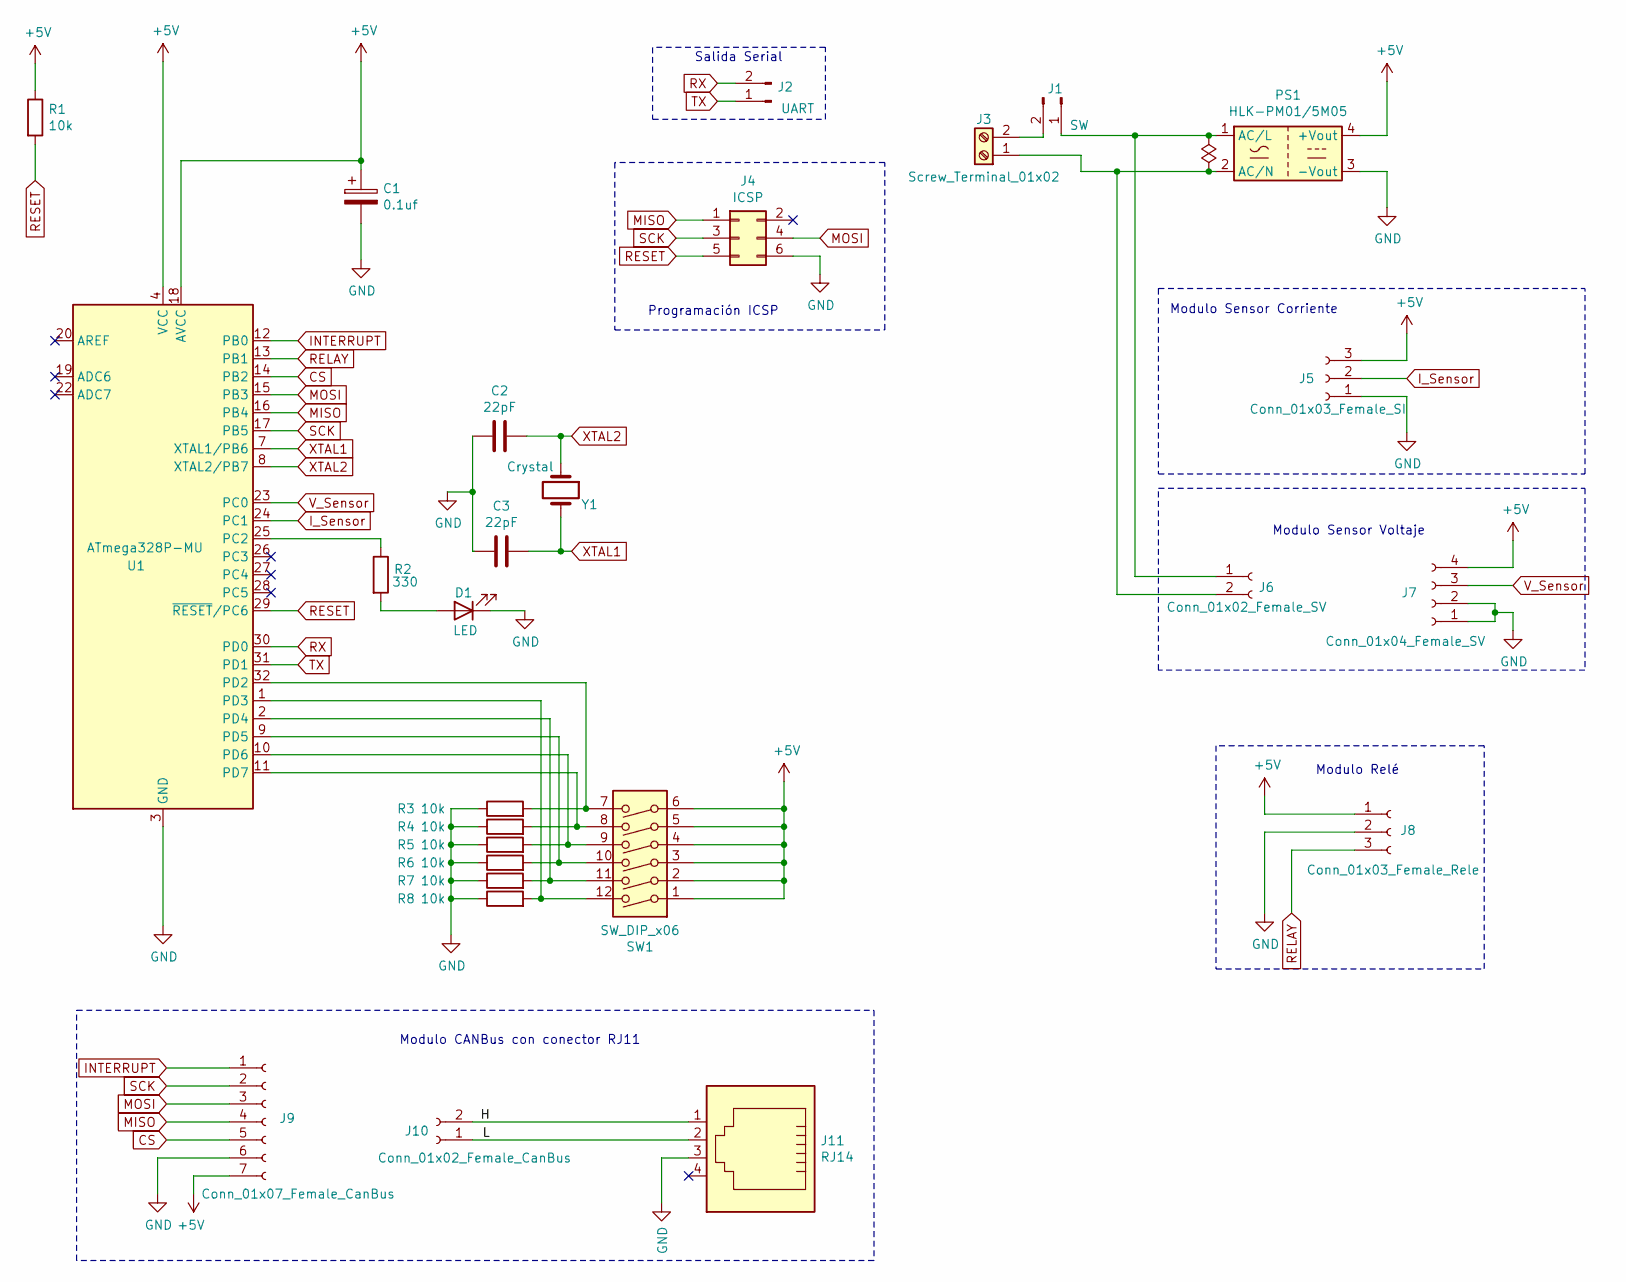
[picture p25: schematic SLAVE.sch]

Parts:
C1: 0.1uf; CP_Radial_D5.0mm_P2.50mm
C2, C3: 22pF; C_0603_1608Metric_Pad1.05x0.95mm_HandSolder
D1: LED; LED_D3.0mm
J1: SW; SolderWire-0.75sqmm_1x02_P4.8mm_D1.25mm_OD2.3mm
J2: UART; PinHeader_1x02_P2.54mm_Vertical
J3: Screw_Terminal_01x02; TerminalBlock_bornier-2_P5.08mm
J4: ICSP; PinHeader_2x03_P2.54mm_Vertical
J5: Conn_01x03_Female_SI; PinHeader_1x03_P2.54mm_Vertical
J6: Conn_01x02_Female_SV; SolderWire-0.75sqmm_1x02_P4.8mm_D1.25mm_OD2.3mm
J7: Conn_01x04_Female_SV; PinHeader_1x04_P2.54mm_Vertical
J8: Conn_01x03_Female_Rele; PinHeader_1x03_P2.54mm_Vertical
J9: Conn_01x07_Female_CanBus; PinHeader_1x07_P2.54mm_Vertical
J10: Conn_01x02_Female_CanBus; PinHeader_1x02_P2.54mm_Vertical
J11: RJ14; RJ14_Connfly_DS1133-S4_Horizontal
PS1: HLK-PM01/5M05; Converter_ACDC_HiLink_HLK-PMxx
R1, R3, R4, R5, R6, R7, R8: 10k; R_0603_1608Metric_Pad1.05x0.95mm_HandSolder
R2: 330; R_0603_1608Metric_Pad1.05x0.95mm_HandSolder
SW1: SW_DIP_x06; SW_DIP_SPSTx06_Piano_10.8x16.8mm_W7.62mm_P2.54mm
U1: ATmega328P-MU; TQFP-32_7x7mm_P0.8mm
Y1: Crystal; Crystal_SMD_HC49-SD

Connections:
+5V: C1.1, J5.3, J7.4, J8.1, J9.7, PS1.4 (+Vout), R1.1, SW1.1, SW1.2, SW1.3, SW1.4, SW1.5, SW1.6, U1.4 (VCC), U1.6 (VCC), U1.18 (AVCC)
/H: J10.2, J11.1
/L: J10.1, J11.2
CS: J9.5, U1.14 (PB2)
GND: C1.2, C2.2, C3.2, D1.1 (K), J4.6, J5.1, J7.1, J7.2, J8.2, J9.6, J11.3, PS1.3 (-Vout), R3.1, R4.1, R5.1, R6.1, R7.1, R8.1, U1.3 (GND), U1.5 (GND), U1.21 (GND), U1.33 (GND)
INTERRUPT: J9.1, U1.12 (PB0)
I_Sensor: J5.2, U1.24 (PC1)
MISO: J4.1, J9.4, U1.16 (PB4)
MOSI: J4.4, J9.3, U1.15 (PB3)
unnamed: D1.2 (A), R2.2
unnamed: J1.1, J6.1, PS1.1 (AC/L)
unnamed: J1.2, J3.2
unnamed: J3.1, J6.2, PS1.2 (AC/N)
unnamed: R2.1, U1.25 (PC2)
unnamed: R3.2, SW1.7, U1.32 (PD2)
unnamed: R4.2, SW1.8, U1.11 (PD7)
unnamed: R5.2, SW1.9, U1.10 (PD6)
unnamed: R6.2, SW1.10, U1.9 (PD5)
unnamed: R7.2, SW1.11, U1.2 (PD4)
unnamed: R8.2, SW1.12, U1.1 (PD3)
RELAY: J8.3, U1.13 (PB1)
RESET: J4.5, R1.2, U1.29 (~RESET~/PC6)
RX: J2.2, U1.30 (PD0)
SCK: J4.3, J9.2, U1.17 (PB5)
TX: J2.1, U1.31 (PD1)
V_Sensor: J7.3, U1.23 (PC0)
XTAL1: C3.1, U1.7 (XTAL1/PB6), Y1.2
XTAL2: C2.1, U1.8 (XTAL2/PB7), Y1.1

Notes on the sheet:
Modulo CANBus con conector RJ11
Modulo Sensor Corriente
Modulo Sensor Voltaje
Programación ICSP
Salida Serial
Modulo Relé



Board: 2 copper layers, 90.0 x 99.6 mm, 27 parts (7 on the bottom side), 28 nets.

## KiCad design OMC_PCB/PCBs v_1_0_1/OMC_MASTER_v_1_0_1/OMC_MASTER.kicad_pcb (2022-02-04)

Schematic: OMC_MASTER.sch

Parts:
J1: Conn_01x08_Female_power; PinHeader_1x08_P2.54mm_Vertical
J2: Conn_01x08_Female_analog1; PinHeader_1x08_P2.54mm_Vertical
J3: Conn_01x08_Female_analog2; PinHeader_1x08_P2.54mm_Vertical
J4: Conn_02x18_Odd_Even; PinHeader_2x18_P2.54mm_Vertical
J5: Conn_01x07_Female_canbus; PinHeader_1x07_P2.54mm_Vertical
J6: Conn_01x02_Female_canbus; PinHeader_1x02_P2.54mm_Vertical
J7: RJ14; RJ14_Connfly_DS1133-S4_Horizontal
J8: Conn_01x08_Female_digital3; PinHeader_1x08_P2.54mm_Vertical
J9: Conn_01x08_Female_digital2; PinHeader_1x08_P2.54mm_Vertical
J10: Conn_01x10_Female_digital1; PinHeader_1x10_P2.54mm_Vertical
J11: Conn_01x06_Female_clock; PinHeader_1x06_P2.54mm_Vertical
U1: LM35-LP; TO-92

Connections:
+5V: J1.5, J4.35, J4.36, J5.7, J11.5, U1.1 (+VS)
CS: J4.7, J5.5
GND: J1.6, J1.7, J4.1, J4.2, J5.6, J7.3, J11.6, U1.3 (GND)
H: J6.2, J7.1
INTERRUPT: J5.1, J9.4
L: J6.1, J7.2
MISO: J4.6, J5.4
MOSI: J4.5, J5.3
SCK: J4.4, J5.2
SCL: J8.1, J11.3
SDA: J8.2, J11.4
SQW: J9.3, J11.2
TEMP: J2.1, U1.2 (Vout)

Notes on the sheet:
Sensor de temperatura LM35
Arduino MEGA 2560
Módulo CANBUS
Reloj DS3231


Board: 2 copper layers, 108.6 x 93.7 mm, 12 parts (1 on the bottom side), 13 nets.

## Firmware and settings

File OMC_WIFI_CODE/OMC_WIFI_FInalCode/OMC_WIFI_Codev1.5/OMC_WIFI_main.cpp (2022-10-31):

#include "OMC_WIFI_main.hpp"

String hostname;


//***************************************************************************************************************************************************************
//*************************************************    FUNCIONES DE LAS PÁGINAS WEB DE AUTOCONNECT     **********************************************************
//***************************************************************************************************************************************************************

// Función para reiniciar los datos en la página de configuración del AP
String onPreConfig(AutoConnectAux& aux, PageArgument& args) {

  inside = false;

  //Se habilita y limpia el campo para introducir la clave
  //aux["passVer"].as<AutoConnectInput>().enable = true;
  aux["passVer"].as<AutoConnectInput>().value  = "";

  //Textos que aparecerán es esta página
  aux["txt01"].as<AutoConnectText>().value = "Para configurar el dispositivo OMC-WIFI, por favor introduzca la clave actual.";


  return String();

}


// Función para indicar los datos iniciales en la página de configuración del AP
String onConfig(AutoConnectAux& aux, PageArgument& args) {

  storage.begin("config", true);       // Se apertura el espacio en memoria flash denominado "storage" para leer (true)

  if ((args.arg("passVer") == storage.getString("pass", "12345678")) or (inside == true)) {

    inside = true;

    //Textos que aparecerán es esta página
    aux["header01"].as<AutoConnectText>().value = "<h2>Cambiar Nombre del Dispositivo</h2>";
    aux["header02"].as<AutoConnectText>().value = "<h2>Cambiar Clave del Dispositivo</h2>";
    aux["header03"].as<AutoConnectText>().value = "<h2>Configurar Dirección IP del Servidor</h2>";
    aux["header04"].as<AutoConnectText>().value = "<h2>Modo de Voltaje</h2>";
    aux["header05"].as<AutoConnectText>().value = "<h2>Límite de Corriente</h2>";
    aux["header06"].as<AutoConnectText>().value = "<h2>Restablecer Credenciales</h2>";

    aux["txt01"].as<AutoConnectText>().value = "Desde este portal podrá configurar algunas características del dispositivo OMC-WIFI.";
    aux["txt02"].as<AutoConnectText>().value = "<p>El <b>nombre</b> debe tener entre 2 y 32 caracteres y solo acepta el guión como caracter especial (NO puede ser el último).</p>";
    aux["txt03"].as<AutoConnectText>().value = "<p>La <b>clave</b> debe tener entre 8 y 16 caracateres.</p>";
    aux["txt04"].as<AutoConnectText>().value = "A continuación deberá introducir la <b>dirección IP</b> del servidor al que se desea conectar (la dirección IP actual es " + storage.getString("server_ip", "0.0.0.0") + ").";
    aux["txt05"].as<AutoConnectText>().value = "Desde este portal podrá cambiar el <b>modo de voltaje</b> a <b>120 voltios</b> o a <b>220 voltios</b> (el modo actual es " + String(storage.getInt("voltMode", 120)) + " voltios). Para ello, por favor verifique el voltaje de su suministro.";
    aux["txt06"].as<AutoConnectText>().value = "Desde este portal podrá cambiar el <b>límite de corriente</b> (el límite actual es " + String(storage.getUChar("corrSup", 10)) + " amperios). Para ello, por favor verifique el consumo de corriente del dispositivo a proteger.";
    aux["txt07"].as<AutoConnectText>().value = "Elija <b>\"Sí\"</b> para restablecer los datos del dispositivo a los de fábrica (APs conectados, credenciales, dirección del servidor IP). <b>ESTE PROCESO ES IRREVERSIBLE</b>";

    aux["voltageMode"].as<AutoConnectSelect>().selected = 0;
    aux["corrLimit"].as<AutoConnectSelect>().selected   = 0;

    //Se habilitan los botones y las entradas de texto
    aux["ssid"].as<AutoConnectInput>().enable         = true;
    aux["pass1"].as<AutoConnectInput>().enable        = true;
    aux["pass2"].as<AutoConnectInput>().enable        = true;
    aux["server"].as<AutoConnectInput>().enable       = true;

    aux["save01"].as<AutoConnectSubmit>().enable      = true;
    aux["save02"].as<AutoConnectSubmit>().enable      = true;
    aux["save03"].as<AutoConnectSubmit>().enable      = true;
    aux["save04"].as<AutoConnectSubmit>().enable      = true;
    aux["voltChange"].as<AutoConnectSubmit>().enable  = true;
    aux["corrChange"].as<AutoConnectSubmit>().enable  = true;

    aux["voltageMode"].as<AutoConnectSelect>().enable = true;
    aux["corrLimit"].as<AutoConnectSelect>().enable   = true;

    aux["resetCred"].as<AutoConnectRadio>().enable    = true;


    //Se limpian las entradas de datos al acceder al directorio
    aux["ssid"].as<AutoConnectInput>().value     = "";
    aux["pass1"].as<AutoConnectInput>().value    = "";
    aux["pass2"].as<AutoConnectInput>().value    = "";
    aux["server"].as<AutoConnectInput>().value   = "";

  }
  else {

    //Textos que aparecerán es esta página
    aux["txt01"].as<AutoConnectText>().value = "La <b>clave introducida</b> es <b>inválida</b>, no podrá configurar el dispositivo.";
    aux["txt02"].as<AutoConnectText>().value = "";
    aux["txt03"].as<AutoConnectText>().value = "";
    aux["txt04"].as<AutoConnectText>().value = "";
    aux["txt05"].as<AutoConnectText>().value = "";
    aux["txt06"].as<AutoConnectText>().value = "";
    aux["txt07"].as<AutoConnectText>().value = "";

    aux["header01"].as<AutoConnectText>().value = "";
    aux["header02"].as<AutoConnectText>().value = "";
    aux["header03"].as<AutoConnectText>().value = "";
    aux["header04"].as<AutoConnectText>().value = "";
    aux["header05"].as<AutoConnectText>().value = "";
    aux["header06"].as<AutoConnectText>().value = "";

    //Se deshabilitan los botones y las entradas de texto
    aux["ssid"].as<AutoConnectInput>().enable         = false;
    aux["pass1"].as<AutoConnectInput>().enable        = false;
    aux["pass2"].as<AutoConnectInput>().enable        = false;
    aux["server"].as<AutoConnectInput>().enable       = false;

    aux["save01"].as<AutoConnectSubmit>().enable      = false;
    aux["save02"].as<AutoConnectSubmit>().enable      = false;
    aux["save03"].as<AutoConnectSubmit>().enable      = false;
    aux["save04"].as<AutoConnectSubmit>().enable      = false;
    aux["voltChange"].as<AutoConnectSubmit>().enable  = false;
    aux["corrChange"].as<AutoConnectSubmit>().enable  = false;

    aux["voltageMode"].as<AutoConnectSelect>().enable = false;
    aux["corrLimit"].as<AutoConnectSelect>().enable   = false;

    aux["resetCred"].as<AutoConnectRadio>().enable    = false;

  }

  storage.end();                       // Se cierra el espacio en memoria flash denominado "storage"

  return String();

}


//Función para validar el cambio de SSID
String onChangeSSID(AutoConnectAux& aux, PageArgument& args) {
  AutoConnectInput& ssid = ap_config["ssid"].as<AutoConnectInput>();                                                                          //Se guarda el elemento AutoConnectInput denominado "ssid" de la página web ap_config, que guarda los datos del nuevo SSID introducidos por el usuario

  aux["header01"].as<AutoConnectText>().value = "<h2>Cambiar Nombre del Dispositivo</h2>";

  storage.begin("config", false);

  if (args.arg("ssid") == "") {                                                                                                               //Si NO se introdujo un SSID
    aux["txtCenter01"].as<AutoConnectText>().value = "NO se detectó ningún cambio en el <b>SSID</b>.\n";                                          //Aparecerá este mensaje en la página web
  }
  else if (ssid.isValid()) {                                                                                                                  //Si se introdujo un SSID y se cumplen las condiciones establecidas
    storage.begin("config", false);                                                                                                             //Se apertura el espacio en memoria flash denominado "storage" para leer y escribir (false)
    storage.putString("ssid", args.arg("ssid"));                                                                                                //Se guarda el SSID introducido por el usuario en la memoria flash
    Serial.println("El <b>SSID</b> ha cambiado a:\n" + storage.getString("ssid", ""));
    storage.end();                                                                                                                              //Se cierra el espacio en memoria flash denominado "storage"

    aux["txtCenter01"].as<AutoConnectText>().value = "El <b>SSID</b> ha cambiado a:\n" + args.arg("ssid");                                        //Aparecerá este mensaje en la página web
  }
  else {                                                                                                                                      //Si se introdujo un SSID pero NO se cumplen las condiciones establecidas
    aux["txtCenter01"].as<AutoConnectText>().value = "El <b>SSID</b> introducido NO cumple las condiciones.\nPor favor intente de nuevo.\n";      //Aparecerá este mensaje en la página web
  }

  aux["txt01"].as<AutoConnectText>().value = "<p><b>ADVERTENCIA:</b> para aplicar los cambios el dispositivo debe ser <b>reiniciado</b>, por lo que el dispositivo conectado al OMC-WIFI será desconectado del suministro eléctrico momentáneamente.</p>";

  return String();

}


// Función para validar el cambio de Contraseña
String onChangePass(AutoConnectAux& aux, PageArgument& args) {

  aux["header02"].as<AutoConnectText>().value = "<h2>Cambiar Clave del Dispositivo</h2>";

  if (args.arg("pass1") == args.arg("pass2")) {                                                                                             //Si las claves introducidas coinciden
    AutoConnectInput& pass = ap_config["pass1"].as<AutoConnectInput>();                                                                       //Se guarda el elemento AutoConnectInput denominado "pass1" de la página web ap_config, que guarda los datos de la nueva clave introducidos por el usuario
    //Verificando que la clave introducida cumple con las condiciones
    if (args.arg("pass1") == "") {                                                                                                            //Si NO se introdujo una clave
      aux["txtCenter01"].as<AutoConnectText>().value = "NO se detectó ningún cambio en la <b>clave</b>.\n";                                           //Aparecerá este mensaje en la página web
    }
    else if (pass.isValid()) {                                                                                                                //Si se introdujo una clave y se cumplen las condiciones establecidas
      storage.begin("config", false);                                                                                                           //Se apertura el espacio en memoria flash denominado "storage" para leer y escribir (false)
      storage.putString("pass", args.arg("pass1"));                                                                                             //Se guarda la clave introducida por el usuario en la memoria flash
      Serial.println("La <b>clave</b> ha cambiado a:\n" + storage.getString("pass", ""));
      storage.end();                                                                                                                            //Se cierra el espacio en memoria flash denominado "storage"

      aux["txtCenter01"].as<AutoConnectText>().value = "La <b>clave</b> ha sido cambiada exitosamente.\n";                                            //Aparecerá este mensaje en la página web
    }
    else {                                                                                                                                    //Si se introdujo una clave pero NO se cumplen las condiciones establecidas
      aux["txtCenter01"].as<AutoConnectText>().value = "La <b>clave</b> introducida NO cumple las condiciones.\nPor favor intente de nuevo.\n";       //Aparecerá este mensaje en la página web
    }
  }
  else {                                                                                                                                    //Si las claves introducidas coinciden
    aux["txtCenter01"].as<AutoConnectText>().value = "Las <b>claves</b> introducidas NO coinciden.\nPor favor intente de nuevo.\n";                 //Aparecerá este mensaje en la página web
  }

  aux["txt01"].as<AutoConnectText>().value = "<p><b>ADVERTENCIA:</b> para aplicar los cambios el dispositivo debe ser <b>reiniciado</b>, por lo que el dispositivo conectado al OMC-WIFI será desconectado del suministro eléctrico momentáneamente.</p>";

  return String();

}


// Función para validar la dirección IP del servidor
String onServerIP(AutoConnectAux& aux, PageArgument& args) {
  AutoConnectInput& server = ap_config["server"].as<AutoConnectInput>();                                                            //Se guarda el elemento AutoConnectInput denominado "server" de la página web ap_config, que guarda los datos de la dirección IP introducidos por el usuario

  aux["header03"].as<AutoConnectText>().value = "<h2>Configurar Dirección IP del Servidor</h2>";

  if (args.arg("server") == "") {                                                                                                   //Si NO se introdujo una dirección IP
    aux["txtCenter01"].as<AutoConnectText>().value = "NO introdujo ninguna <b>dirección IP</b>.\n";                                         //Aparecerá este mensaje en la página web
  }
  else if (server.isValid()) {                                                                                                      //Si se introdujo una dirección IP y se cumplen las condiciones establecidas
    storage.begin("config", false);                                                                                                   //Se apertura el espacio en memoria flash denominado "storage" para leer y escribir (false)
    storage.putString("server_ip", args.arg("server"));                                                                               //Se guarda la dirección IP en la memoria flash
    Serial.println("La dirección IP del servidor ha cambiado a:\n" + storage.getString("server_ip", ""));
    storage.end();                                                                                                                    //Se cierra el espacio en memoria flash denominado "storage"

    MQTT_HOST.fromString(args.arg("server"));
    mqttClient.setServer(MQTT_HOST, MQTT_PORT);

    //mqttSetUp();
    //connectToMqtt();
    xTimerStart(mqttReconnectTimer, 0); // Para reconectarnos, el temporizador intenta reconectar una vez se desborda

    aux["txtCenter01"].as<AutoConnectText>().value = "La <b>dirección IP del servidor</b> ha cambiado a:\n" + args.arg("server");           //Aparecerá este mensaje en la página web
  }
  else {                                                                                                                            //Si se introdujo una dirección IP pero NO se cumplen las condiciones establecidas
    aux["txtCenter01"].as<AutoConnectText>().value = "La <b>dirección IP</b> introducida es inválida.\nPor favor intente de nuevo.\n";      //Aparecerá este mensaje en la página web
  }

  return String();

}


String onVoltageMode(AutoConnectAux& aux, PageArgument& args) {

  storage.begin("config", false);

  switch (args.arg("voltageMode").toInt()) {

    case 120:
      voltMode = 120;
      aux["txtCenter01"].as<AutoConnectText>().value = "Modo de voltaje cambiado a <b>" + String(voltMode) + " voltios</b>";
      break;

    case 220:
      voltMode  = 220;
      aux["txtCenter01"].as<AutoConnectText>().value = "Modo de voltaje cambiado a <b>" + String(voltMode) + " voltios</b>";
      break;

    default:
      aux["txtCenter01"].as<AutoConnectText>().value = "No se seleccionó ninguna opción de cambio";
      break;

  }

  voltInf  = voltMode * lowFactor;                              //Se define el voltaje de corte inferior en base al modo de voltaje
  voltSup  = voltMode * highFactor;                              //Se define el voltaje de corte superior en base al modo de voltaje

  storage.putInt("voltMode", voltMode);

  storage.end();

  return String();

}


String onCurrentLimit(AutoConnectAux& aux, PageArgument& args) {

  storage.begin("config", false);

  switch (args.arg("corrLimit").toInt()) {

    case 1:
      corrSup = 1;
      aux["txtCenter01"].as<AutoConnectText>().value = "Límite de corriente cambiado a <b>" + String(corrSup) + " amperios</b>";
      break;

    case 2:
      corrSup = 2;
      aux["txtCenter01"].as<AutoConnectText>().value = "Límite de corriente cambiado a <b>" + String(corrSup) + " amperios</b>";
      break;

    case 3:
      corrSup = 3;
      aux["txtCenter01"].as<AutoConnectText>().value = "Límite de corriente cambiado a <b>" + String(corrSup) + " amperios</b>";
      break;

    case 4:
      corrSup = 4;
      aux["txtCenter01"].as<AutoConnectText>().value = "Límite de corriente cambiado a <b>" + String(corrSup) + " amperios</b>";
      break;

    case 5:
      corrSup = 5;
      aux["txtCenter01"].as<AutoConnectText>().value = "Límite de corriente cambiado a <b>" + String(corrSup) + " amperios</b>";
      break;

    case 6:
      corrSup = 6;
      aux["txtCenter01"].as<AutoConnectText>().value = "Límite de corriente cambiado a <b>" + String(corrSup) + " amperios</b>";
      break;

    case 7:
      corrSup = 7;
      aux["txtCenter01"].as<AutoConnectText>().value = "Límite de corriente cambiado a <b>" + String(corrSup) + " amperios</b>";
      break;

    case 8:
      corrSup = 8;
      aux["txtCenter01"].as<AutoConnectText>().value = "Límite de corriente cambiado a <b>" + String(corrSup) + " amperios</b>";
      break;

    case 9:
      corrSup = 9;
      aux["txtCenter01"].as<AutoConnectText>().value = "Límite de corriente cambiado a <b>" + String(corrSup) + " amperios</b>";
      break;

    case 10:
      corrSup = 10;
      aux["txtCenter01"].as<AutoConnectText>().value = "Límite de corriente cambiado a <b>" + String(corrSup) + " amperios</b>";
      break;

    default:
      if (args.arg("corrLimit") == "0.5") {

        corrSup = 0.5;
        aux["txtCenter01"].as<AutoConnectText>().value = "Límite de corriente cambiado a <b>" + String(corrSup) + " amperios</b>";

      }
      else {
        aux["txtCenter01"].as<AutoConnectText>().value = "No se seleccionó ninguna opción de cambio";

      }
      break;

  }

  storage.putUChar("corrSup", corrSup);

  storage.end();

  return String();

}


// Función para validar el reinicio de credenciales
String onCredentialReset(AutoConnectAux& aux, PageArgument& args) {

  aux["header04"].as<AutoConnectText>().value = "<h2>Restablecer Credenciales</h2>";

  storage.begin("config", false);                                                                                 //Se apertura el espacio en memoria flash denominado "storage" para leer y escribir (false)

  if (args.arg("resetCred") == "Sí") {                                               //Si la clave introducida por el usuario coincide con la actual del ESP32

    credReset();

    aux["txtCenter01"].as<AutoConnectText>().value = "Los <b>datos guardados</b> han sido restablecidas exitosamente.\n";    //Aparecerá este mensaje en la página web
    aux["txt01"].as<AutoConnectText>().value = "<p><b>ADVERTENCIA:</b> para aplicar los cambios el dispositivo debe ser <b>reiniciado</b>, por lo que el dispositivo conectado al OMC-WIFI será desconectado del suministro eléctrico momentáneamente.</p>";

  }
  else {                                                                                                          //Si la clave introducida por el usuario coincide con la actual del ESP32
    aux["txtCenter01"].as<AutoConnectText>().value = "Los <b>datos guardados</b> se han mantenido.";                  //Aparecerá este mensaje en la página web
    aux["txt01"].as<AutoConnectText>().value = "";

  }

  storage.end();                                                                                                  //Se cierra el espacio en memoria flash denominado "storage"


  return String();

}
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
void loop() {

  uint32_t    oldTicks = 0;

  while (true) {
    if ((xTaskGetTickCount() - oldTicks) > 0) {

      uptime = uptime + ((int)(xTaskGetTickCount() - oldTicks)) / 1000;

    }
    else {

      uptime =  + ((int)xTaskGetTickCount()) / 1000;

    }

    oldTicks = xTaskGetTickCount();

  }

}

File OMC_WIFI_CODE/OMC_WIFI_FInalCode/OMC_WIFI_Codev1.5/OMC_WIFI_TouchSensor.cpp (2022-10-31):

#include "OMC_WIFI_TouchSensor.hpp"

uint32_t ticks = 0;

PZEM004Tv30 pzem2(Serial2, 16, 17);

void touchInterrupt() {

  if ((eTaskGetState(xTouchHandle) == eSuspended)) {

//    Serial.println("Interrupted");

    vTaskDelay(10 / portTICK_PERIOD_MS);
    touch_pad_intr_disable();

    vTaskDelay(10 / portTICK_PERIOD_MS);
    vTaskResume(xTouchHandle);

  }

}


void touchSetUp() {

  touchAttachInterrupt(TOUCH_SENSOR, touchInterrupt, THRESHOLD);

}

//Tarea p
void touchTask(void *touchParameter) {

//  Serial.println("Touch Task created");

  while (true) {

    ticks = xTaskGetTickCount();

    while ((touchRead(TOUCH_SENSOR) < THRESHOLD) and (xTaskGetTickCount() - ticks <= 10000)) {

    }

    ticks = xTaskGetTickCount() - ticks;

//    Serial.println(ticks);


    if ((ticks >= AP_MODE_THRESHOLD) and (ticks < CRED_RESET_THRESHOLD)) {

      if (WiFi.softAPdisconnect()) {                          // Si el ESP32 está en modo AP/Estación

        esp_wifi_set_mode(WIFI_MODE_STA);                       // Se cambia el modo del ESP32 a Estación

//        Serial.println("Cambiado a modo Estación");

      }
      else {                                                  // Si el ESP32 está en modo Estación

        String ssid = "OMC-WIFI-" + omcID;

        storage.begin("config", true);                          // Se apertura el espacio en memoria flash denominado "storage" para leer (true)

        esp_wifi_set_mode(WIFI_MODE_APSTA);                     //Se cambia el modo del ESP32 a AP/Estación

        WiFi.softAPConfig(IPAddress(172, 16, 16, 1), IPAddress(172, 16, 16, 1), IPAddress(255, 255, 255, 0));
        WiFi.softAP(storage.getString("ssid", ssid.c_str()).c_str(), storage.getString("pass", "12345678").c_str());    //Se inicializa el AP con las credenciales guardadas
//        Serial.println("Cambiado a modo AP/Estación");

        storage.end();

      }

    }
    //    else if ((ticks >= REBOOT_THRESHOLD) and (ticks < CRED_RESET_THRESHOLD)) {
    //
    //      //Serial.println("Rebooting OMC-WIFI in 5 seconds...");
    //
    //      Serial.end();
    //      vTaskDelay(100 / portTICK_PERIOD_MS);
    //
    //      xTimerDelete(publishTimer, 0);
    //      xTimerDelete(mqttReconnectTimer, 0);
    //      xTimerDelete(timerRecuperacion, 0);
    //      xTimerDelete(timerSecundario, 0);
    //      vTaskDelay(100 / portTICK_PERIOD_MS);
    //
    //      vTaskDelete(xAutoConnectHandle);
    //      vTaskDelete(xGreenLedHandle);
    //      vTaskDelete(xRedLedHandle);
    //      vTaskDelete(xTouchHandle);
    //      vTaskDelay(100 / portTICK_PERIOD_MS);
    //
    //      ESP.restart();
    //
    //    }
    else if (ticks >= CRED_RESET_THRESHOLD) {

      //Serial.println("Clearing credentials and rebooting OMC-WIFI in 5 seconds...");
      pzem2.resetEnergy();
      credReset();
//      Serial.println("Credenciales borradas");
      Serial.end();
      Serial2.end();
      vTaskDelay(100 / portTICK_PERIOD_MS);

      xTimerDelete(publishTimer, 0);
      xTimerDelete(mqttReconnectTimer, 0);
      xTimerDelete(timerRecuperacion, 0);
      xTimerDelete(timerSecundario, 0);
      vTaskDelay(100 / portTICK_PERIOD_MS);

      vTaskDelete(xAutoConnectHandle);
      vTaskDelete(xReadHandle);
      vTaskDelete(xGreenLedHandle);
      vTaskDelete(xRedLedHandle);
      vTaskDelay(100 / portTICK_PERIOD_MS);

      esp_task_wdt_init(1, true);
      esp_task_wdt_add(NULL);
      vTaskDelay(100 / portTICK_PERIOD_MS);

      ESP.restart();

    }
    else {

//      Serial.println("Se presionó el botón por menos de 5 segundos");

    }


    touch_pad_intr_enable();          //Se habilita nuevamente la interrupción
    vTaskSuspend(NULL);               //Se suspende la tarea del Touch Sensor

  }

}

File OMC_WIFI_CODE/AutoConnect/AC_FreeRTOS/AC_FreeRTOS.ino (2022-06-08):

#include <WiFi.h>
#include <WebServer.h>
#include <AutoConnect.h>
#include <AutoConnectCredential.h>
#include <Preferences.h>
#include <nvs_flash.h>
#include <AsyncMqttClient.h>
//#include "freertos/FreeRTOS.h"
//#include "freertos/timers.h"

int i = 0;


//***************************************************************************************************************************************************************
//******************************************************    VARIABLES Y CONSTANTES PARA CLIENTE MQTT     ********************************************************
//***************************************************************************************************************************************************************
//
//#define WIFI_SSID "dos-desktop"
//#define WIFI_PASSWORD "8RlGCKQL"

//#define WIFI_SSID "Thorondor"
//#define WIFI_PASSWORD "n140862m041260n200689m170697gizmokingdom"
//#define MQTT_HOST IPAddress(192, 168, 0, 50)
//#define MQTT_PORT 1883

#define   MQTT_PORT 1883
IPAddress MQTT_HOST;

AsyncMqttClient mqttClient;
TimerHandle_t mqttReconnectTimer;
TimerHandle_t wifiReconnectTimer;
TimerHandle_t publishTimer;

//***************************************************************************************************************************************************************
//***************************************************************************************************************************************************************
//***************************************************************************************************************************************************************


//***************************************************************************************************************************************************************
//*************************************************    VARIABLES, CONSTANTES Y ARREGLOS PARA LECTURA ANALÓGICA     **********************************************
//***************************************************************************************************************************************************************

uint32_t promedioVolt = 0;            // Promedio de las mediciones analógicas, usado para eliminar nivel DC
uint32_t promedioCorr = 0;

float lecturaVolt[2500];              // Arreglo con valores del ADC para promedio (Ventana)
float lecturaCorr[2500];              // Arreglo con valores del ADC para promedio (Ventana)
float cuadradoVolt[2500];             // Arreglo con valores cuadrados que se sumarán (Ventana)
float cuadradoCorr[2500];             // Arreglo con valores cuadrados que se sumarán (Ventana)
int   pos = 0;                          // Posición en la ventana de los valores cuadrados

const float multVolt = 2.8 * 2.8;   // Factor de escala para medir voltaje 2.75
const float multCorr = 108 * 108;     // Factor de escala para medir corriente 108

float rmsVolt = 0;                    // Valor RMS Voltaje
float rmsCorr = 0;                    // Valor RMS Corriente

//***************************************************************************************************************************************************************
//***************************************************************************************************************************************************************
//***************************************************************************************************************************************************************



//***************************************************************************************************************************************************************
//*************************************************    VARIABLES Y CONSTANTES PARA CONTROLAR EL RELAY     *******************************************************
//***************************************************************************************************************************************************************

const int relayPin         = 32;      //Pin que se empleará para el relay

uint8_t voltSup = 135;                // Máximo voltaje permitido
uint8_t voltInf = 100;                // Mínimo voltaje permitido
uint8_t corrSup = 7;                 // Máxima corriente permitida

uint8_t tiempoRecuperacion = 10;      // Tiempo requerido permitir paso de corriente luego de una falla o un reinicio (segundos)

boolean relay = LOW;                  // Estado del relay (software)
boolean pasoElTiempo = 0;             // Indica si transcurrió el tiempo de recuperación

boolean controlGlobalRelay = true;    // Control Global del Relé
// Si controlGlobalRelay = 0 entonces estamos forzando a que se mantenga apagado sin importar el voltaje o la corriente.
// Si controlGlobalRelay = 1 entonces estamos trabajando de manera normal con los márgenes de voltaje y corriente normales.

TimerHandle_t timerRecuperacion;      // Temporizador, se desborda y ejecuta pasoTiempoRecuperacion() luego de que trascurran "tiempoRecuperacion" segundos

//***************************************************************************************************************************************************************
//***************************************************************************************************************************************************************
//***************************************************************************************************************************************************************



//***************************************************************************************************************************************************************
//*******************************************************    CONSTANTES Y CONSTRUCTORES PARA AUTOCONNECT     ****************************************************
//***************************************************************************************************************************************************************

WebServer         Server;             // Constructor del servidor web del ESP32
AutoConnect       Portal(Server);     // Constructor del portal captivo del ESP32
AutoConnectConfig config;             // Constructor de las configuraciones del AutoConnect

Preferences       storage;            // Espacio en memoria para guardar los datos necesarios

String hostname;                        // Variable donde se guardan los últimos 3 bytes de la dirección MAC (ESP.getEfuseMAC extrae los bytes deordenados)

boolean inside     = false;
boolean connServer = false;
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

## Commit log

2022-02-04 Agregado:
    Diagramas esquematicos y de PCB del proyecto OMC, como referencia.
    [OMC_CONNECTION_BOARD-B_Cu.gbl, OMC_CONNECTION_BOARD-B_Mask.gbs, OMC_CONNECTION_BOARD-B_Paste.gbp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]
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2022-02-11 Creados archivos iniciales para PCB
    Se crearon 2 archivos para trabajar en paralelo
    [PCB_Carlos.kicad_pcb, PCB_Carlos.kicad_sch, PCB_David.kicad_pcb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]
2022-02-11 Creación nuevo documento KiCad
    - 2 archivos de KiCad
    + Archivo de KiCad para trabajar en conjunto
    [OMC_WIFI_PCB.kicad_pcb, OMC_WIFI_PCB.sch, PCB_Carlos.kicad_pcb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]
2022-02-11 Actualización Esquemático
    + Módulo ZMPT101B
    + Módulo ACS712
    + ESP32 DevKitv1
    + Fuente de alimentación
    + Módulo Relay
    [OMC_WIFI_PCB.sch]
2022-02-14 Actualización esquemático y PCB
    + Modificación del esquemático
    + Adición de footprints
    + Circuito amplificador para el relay
    + Modelo PCB del ZMPT101B
    + Adición de Librerías
    [OMC_WIFI_PCB.kicad_pcb, OMC_WIFI_PCB.sch]
2022-02-15 Reestructuración PCB
    > Cambio de posiciones
    + Anexar medidas
    - Eliminar LM741
    [OMC_WIFI_PCB.sch]
2022-02-15 Actualización PCB
    + Medidas de ZMPT101B
    + Medidas Módulo Relay
    [OMC_WIFI_PCB.kicad_pcb, OMC_WIFI_PCB.sch]
2022-02-16 Actualización PCB
    + Medidas ACS712
    - Conexión 5V al switch
    [OMC_WIFI_PCB.kicad_pcb, OMC_WIFI_PCB.sch]
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2022-02-16 Actualización PCB
    + Pistas digitales
    > Modificación de Tags
    > Rediseño de la PCB
    [OMC_WIFI_PCB.kicad_pcb, OMC_WIFI_PCB.sch]
2022-02-17 Actualización PCB
    +Plano de Tierra
    > Rediseño PCB para utilizar un solo conector
    > Redistribución de pistas
    [OMC_WIFI_PCB.kicad_pcb, OMC_WIFI_PCB.sch]
2022-02-18 Actualización PCB
    + Jumper para ACS
    + Fusible
    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
    [OMC_WIFI_PCB.kicad_pcb, OMC_WIFI_PCB.sch]
2022-02-21 Diseño PCB
    + Archivos Gerber y Drill
    - Divisor de tensión del ACS712
    [OMC_WIFI_PCB-B_Cu.gbl, OMC_WIFI_PCB-B_Mask.gbs, OMC_WIFI_PCB-B_Paste.gbp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]
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2022-02-22 Diseño PCB
    > Modificación de dimensiones ESP32 Devkit V1 en PCB.
    > Modificadas las dimensiones de la placa.
    + Pistas entre puntas de fusible para aumentar área de contacto con soldadura.
    > Generados nuevos archivos gerber
    [OMC_WIFI_PCB-B_Cu.gbl, OMC_WIFI_PCB-B_Mask.gbs, OMC_WIFI_PCB-B_Paste.gbp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]
2022-02-22 Actualización PCB
    > Actualización esquemático.
    [OMC_WIFI_PCB.sch]
2022-02-22 Modificación PCB
    > Redimensionamiento Relay
    > Redimensionamiento ACS
    [OMC_WIFI_PCB-B_Cu.gbl, OMC_WIFI_PCB-B_Mask.gbs, OMC_WIFI_PCB-B_Paste.gbp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]
2022-02-23 Actualización PCB
    + Pista de potencia F. Cu
    [OMC_WIFI_PCB-B_Cu.gbl, OMC_WIFI_PCB-B_Mask.gbs, OMC_WIFI_PCB-B_Paste.gbp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]
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2022-03-04 Reestructuración Repositorio
    > Reestructuración del respositorio para mayor orden y legibilidad
    + Creación de README.md
    [OMC_CONNECTION_BOARD-B_Cu.gbl, OMC_CONNECTION_BOARD-B_Mask.gbs, OMC_CONNECTION_BOARD-B_Paste.gbp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]
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2022-03-09 Actualización AutoConnect
    + Guardar clave
    + Resetear credenciales de fábrica
    [AutoConnect.ino]
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2022-03-23 Diseño PCB 1.1
    > Modificación esquemático
    [OMC_WIFI_PCB.kicad_pcb, OMC_WIFI_PCB.sch]
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2022-03-28 Librerías para clavijas
    + Esquemático y footprint de clavija macho
    + Esquemático y footprint de clavija hembra
    [OMC_WIFI_PCB.kicad_pcb]
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2022-03-31 Actualización PCB
    > Divisores de tensión
    > Nuevos Gerbers
    [OMC_WIFI_PCB-B_Cu.gbl, OMC_WIFI_PCB-B_Mask.gbs, OMC_WIFI_PCB-B_Paste.gbp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]
2022-04-05 Actualización AutoConnect
    + Modificación Labels en página principal
    + Modificación de ítems que aparecen en la página principal
    [OMC_WIFI_PCB.sch]
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2022-04-11 Actualización PCB y AutoConnect
    > Cambios en código para compatibilidad entre clientes MQTT
    > Agregados modelos 3D Fuente y Relay
    [OMC_WIFI_PCB.kicad_pcb]
2022-04-12 Actualización PCB y nueva librería para plug macho
    [OMC_WIFI_PCB.kicad_pcb, OMC_WIFI_PCB.sch]
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2022-04-26 Modelos 3D de clavijas
    +Creación de modelos 3D para Clavijas
    [OMC_WIFI_PCB.kicad_pcb, OMC_WIFI_PCB.sch]
2022-05-02 Actualización PCB
    > Creación de Versión 1.3 con espacio para toroide
    [OMC_WIFI_PCB.kicad_pcb, OMC_WIFI_PCB.sch]
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2022-05-10 Creación de versión 1.4 PCB
    > Cambio en diseño para paso de cable por toroide.
    [OMC_WIFI_PCB.kicad_pcb, OMC_WIFI_PCB.sch]
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2022-05-23 Creación de nuevas librerías conectores AC
    Creación de librería 2D para conectores macho y hembra para AC
    [OMC_WIFI_PCB.kicad_pcb, OMC_WIFI_PCB.sch]
2022-05-24 Actualización PCB
    Nuevo diseño (v1.5) con piezas nuevas para AC
    [OMC_WIFI_PCB.kicad_pcb, OMC_WIFI_PCB.sch]
2022-05-25 Actualización PCB
    > Cambio en polaridad de transistor
    > Cambio en planos de tierra y B.Mask
    > Cambio en librería de conector hembra AC
    [OMC_WIFI_PCB.kicad_pcb, OMC_WIFI_PCB.sch]
2022-05-31 Creación de GERBERS PCB v1.5
    Se incluyen cambios pequeños en la PCB:
    > Cambio al transistor MMBT3904
    > Cambio en puntos de soldadura para los cables del toroide.
    [OMC_WIFI_PCB-B_Cu.gbl, OMC_WIFI_PCB-B_Mask.gbs, OMC_WIFI_PCB-B_Paste.gbp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]
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2022-08-24 Cambios código OMC
    > Cambió mensaje de bienvenida a pagina de AutoConnect
    > Un cambio de IP de servidor activa timer de MQTT en lugar de llamar a connectToMQTT()
    > Se arregló la manera de hacer reinicio del contador de energia declarando otro objeto pzem con la misma dirección
    > No se intenta conectar a MQTT si se tiene 0.0.0.0 como IP
    > Se agregó la el algoritmo de desconexión/rechazo al recibir el [ID]99
    [OMC_WIFI_main.cpp, OMC_WIFI_mqtt.cpp]
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2022-09-02 OMC Final Code v1.5
    > Cambio timers para evitar crash del dispositivo 01
    [BOM - OMC_WIFI.xlsx]
2022-09-02 Actualización servidor y código
    >Cambios servidor
    > Cambio para evitar problemas con periodo 0 en timerSecundario
    > Intento de arreglar problema al reiniciar equipo
    [OMC_WIFI_mqtt.cpp]
2022-09-06 OMC Finalk COde v1.5
    > Arreglar reinicio
    > Arreglar lectura
    [OMC_WIFI_Leds.cpp, OMC_WIFI_Leds.hpp, OMC_WIFI_TouchSensor.cpp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]
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2022-09-15 Actualización código OMC
    > Se modificó una parte del código de MQTT. Había algo que funcionaba por obra y gracia del Espíritu Santo (por alguna razón dentro de un arreglo de 4 caracteres cabían 6 caracteres). Esto dio problemas meses después en un solo dispositivo, por lo cual se tuvo que cambiar.
    + Se agregaron mensajes para notificar si llegó un mensaje MQTT en el OMC
    [OMC_WIFI_mqtt.cpp]
2022-09-21 OMC Final Code v1.5
    > Restart issues
    [OMC_WIFI_TouchSensor.cpp, OMC_WIFI_main.cpp, OMC_WIFI_mqtt.cpp]
2022-10-31 OMC Final Code v1.5
    + Restart Fix
    [OMC_WIFI_Leds.cpp, OMC_WIFI_TouchSensor.cpp, OMC_WIFI_main.cpp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]
